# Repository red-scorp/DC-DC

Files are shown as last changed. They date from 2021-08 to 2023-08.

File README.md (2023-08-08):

```
 ____  _____   _ ____  _____    _____           _         _   
|    \|     | / |    \|     |  |  _  |___ ___  |_|___ ___| |_ 
|  |  |   --|/ /|  |  |   --|  |   __|  _| . | | | -_|  _|  _|
|____/|_____|_/ |____/|_____|  |__|  |_| |___|_| |___|___|_|  
                                             |___|
```

# DC/DC project

This project is intended to implement some simple multipurpose DC/DC buck and buck-boost converters from easy available components.
This project also features Excel based component values calculator.

I've stared this project to create stable and high quality DC/DC module for my private projects, covering most common usecases:

- Step-down to most common fixed voltages 3.3V, 5V and 12V up to 5A
- Step-up/down from 1.8V-5.5V to 3.3V and 5V up to 3A
- Step-up/down from 2.5V-12V to 3.3V and 5V up to 1A

## DCDC-12V5V5A

**DCDC-12V5V5A** is simple DC/DC step-down converter with fixed output 5V.
When used for more than 1A current it's recommended to glue a heat sink about 20x20mm in a middle of the bottom side of the board.

Preview:

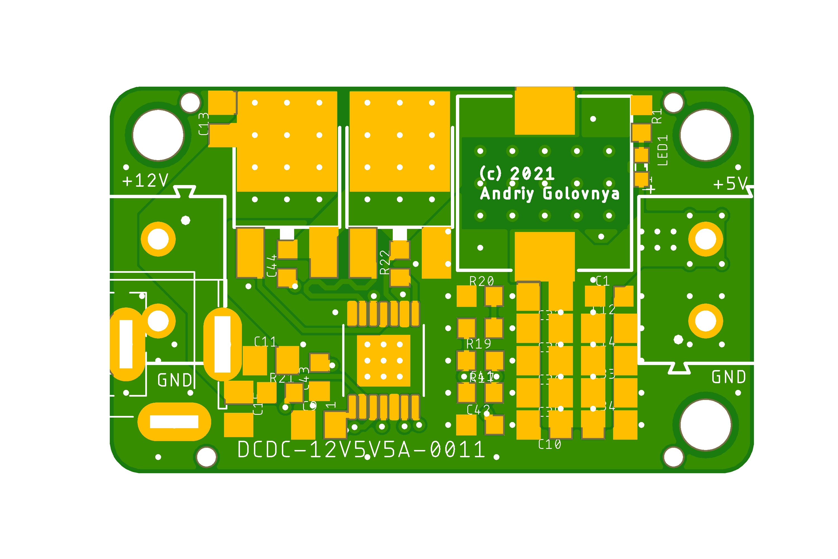
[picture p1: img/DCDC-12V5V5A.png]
DCDC-12V5V5A preview


[Schematics in PDF format](doc/DCDC-12V5V5A.pdf)

Features:

- Input: **12V (7V-24V)**
- Output: **5V**
- Current: **5A (peak 10A)**
- Switching: **500kHz**
- Efficiency: **up to 90%**
- Board size: **40x24mm**
- Based on: **Ti LM3150**

CAM files are available.
BoM and PnP files for JLCPCB are available.

## DCDC-12V3V5A

**DCDC-12V3V5A** is simple DC/DC step-down converter with fixed output 3.3V.
When used for more than 1A current it's recommended to glue a heat sink about 20x20mm in a middle of the bottom side of the board.

Preview:

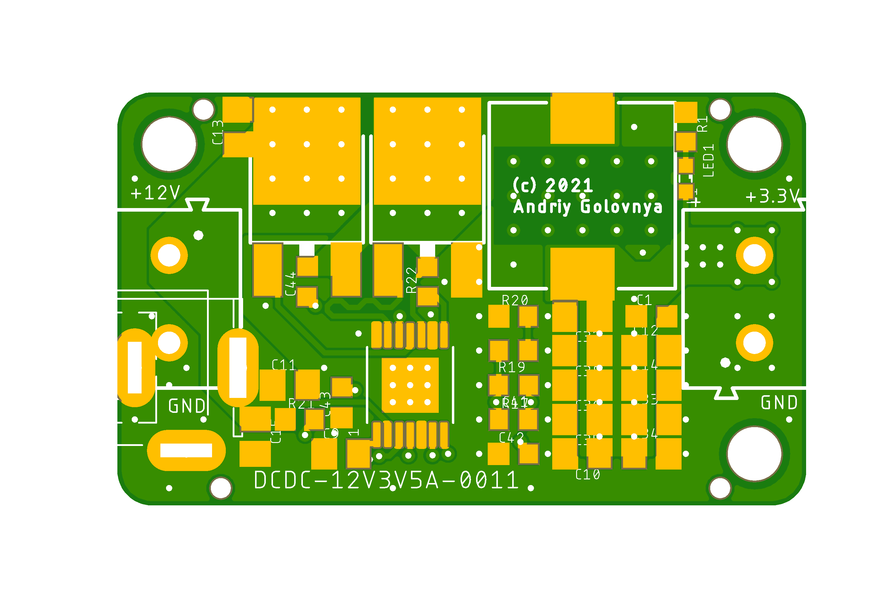
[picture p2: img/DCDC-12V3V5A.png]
DCDC-12V3V5A preview


[Schematics in PDF format](doc/DCDC-12V3V5A.pdf)

Features:

- Input: **12V (5V-24V)**
- Output: **3.3V**
- Current: **5A (peak 10A)**
- Switching: **600kHz**
- Efficiency: **up to 90%**
- Board size: **40x24mm**
- Based on: **Ti LM3150**

CAM files are available.
BoM and PnP files for JLCPCB are available.

## DCDC-18V12V5A

**DCDC-18V12V5A** is simple DC/DC step-down converter with fixed output 12V.
When used for more than 1A current it's recommended to glue a heat sink about 20x20mm in a middle of the bottom side of the board.

Preview:

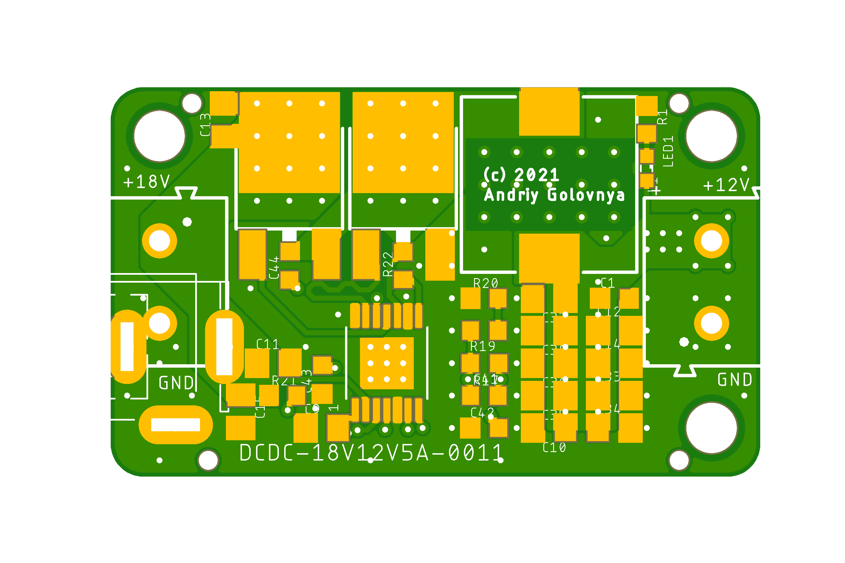
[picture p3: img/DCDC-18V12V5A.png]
DCDC-18V12V5A preview


[Schematics in PDF format](doc/DCDC-18V12V5A.pdf)

Features:

- Input: **18V (14V-24V)**
- Output: **12V**
- Current: **5A (peak 10A)**
- Switching: **500kHz**
- Efficiency: **up to 90%**
- Board size: **40x24mm**
- Based on: **Ti LM3150**

CAM files are available.
BoM and PnP files for JLCPCB are available.

## DCDC-18VXV5A

**DCDC-18VXV5A** is simple DC/DC step-down converter with selectable output 2-12V.
When used for more than 1A current it's recommended to glue a heat sink about 20x20mm in a middle of the bottom side of the board.

Preview:

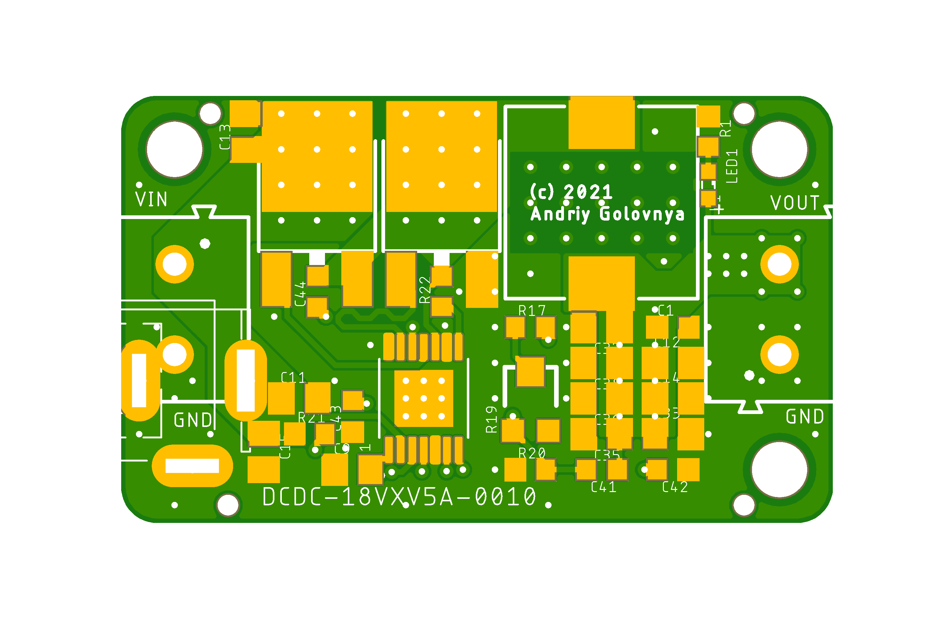
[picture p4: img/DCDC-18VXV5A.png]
DCDC-18VXV5A preview


[Schematics in PDF format](doc/DCDC-18VXV5A.pdf)

Features:

- Input: **18V (5V-24V)**
- Output: **2-12V**
- Current: **5A (peak 10A)**
- Switching: **500kHz**
- Efficiency: **up to 90%**
- Board size: **40x24mm**
- Based on: **Ti LM3150**

CAM files are available.
BoM and PnP files for JLCPCB are available.

## DCDC-5V5V3A

**DCDC-5V5V3A** is simple DC/DC step-up/down converter with selectable fixed output 3.3/5V.
When used for more than 1A current it's recommended to glue a heat sink about 20x20mm in a middle of the bottom side of the board.

Preview:

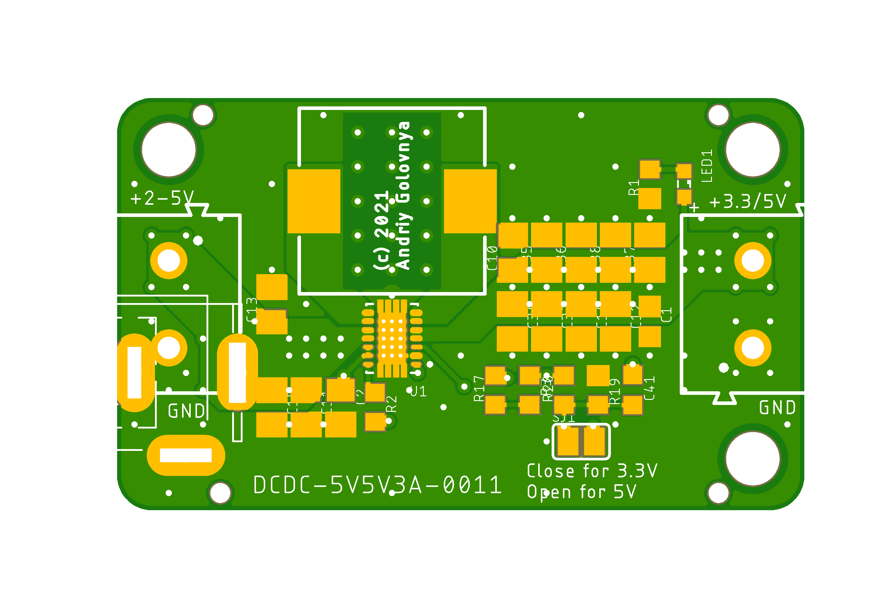
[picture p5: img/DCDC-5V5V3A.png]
DCDC-5V5V3A preview


[Schematics in PDF format](doc/DCDC-5V5V3A.pdf)

Features:

- Input: **1.8-5.5V**
- Output: **3.3/5V (select)**
- Current: **3A (peak 5A)**
- Switching: **2.4MHz**
- Efficiency: **up to 90%**
- Board size: **40x24mm**
- Based on: **Ti TPS63020**

CAM files are available.
BoM and PnP files for JLCPCB are available.

## DCDC-5VXV3A

**DCDC-5VXV3A** is simple DC/DC step-up/down converter with selectable output 1.2-5V.
When used for more than 1A current it's recommended to glue a heat sink about 20x20mm in a middle of the bottom side of the board.

Preview:

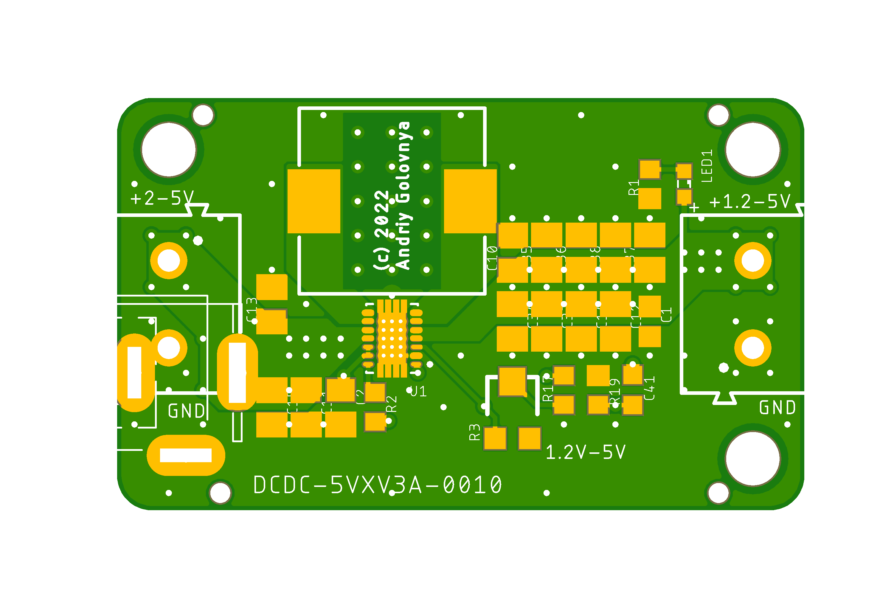
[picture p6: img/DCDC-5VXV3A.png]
DCDC-5VXV3A preview


[Schematics in PDF format](doc/DCDC-5VXV3A.pdf)

Features:

- Input: **1.8-5.5V**
- Output: **1.2-5V**
- Current: **3A (peak 5A)**
- Switching: **2.4MHz**
- Efficiency: **up to 90%**
- Board size: **40x24mm**
- Based on: **Ti TPS63020**

CAM files are available.
BoM and PnP files for JLCPCB are available.

## DCDC-12V5V1A

**DCDC-12V5V1A** is simple DC/DC step-up/down converter with selectable fixed output 3.3/5V.
When used for more than 1A current it's recommended to glue a heat sink about 20x20mm in a middle of the bottom side of the board.

Preview:

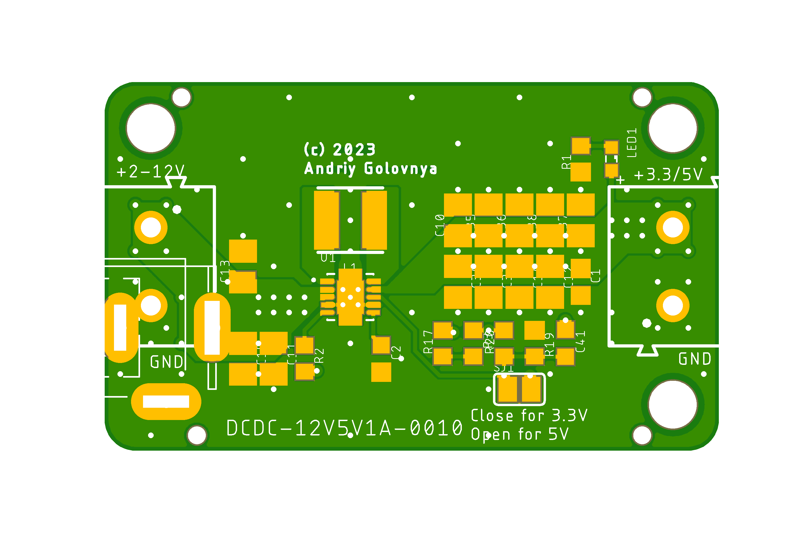
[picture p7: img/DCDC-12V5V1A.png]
DCDC-12V5V1A preview


[Schematics in PDF format](doc/DCDC-12V5V1A.pdf)

Features:

- Input: **2.5-12V**
- Output: **3.3/5V (select)**
- Current: **1A (peak 2A)**
- Switching: **2.4MHz**
- Efficiency: **up to 90%**
- Board size: **40x24mm**
- Based on: **Ti TPS63060**

CAM files are available.
BoM and PnP files for JLCPCB are available.

## DCDC-BASE-X2A

**DCDC-BASE-X2A** is base board for 2 DC/DC modules with common input and two separate outputs.
When used for more than 1A current it's recommended to glue a heat sinks about 20x20mm in a middle of the bottom side of DCDC boards before soldering them to the base board.

Preview:

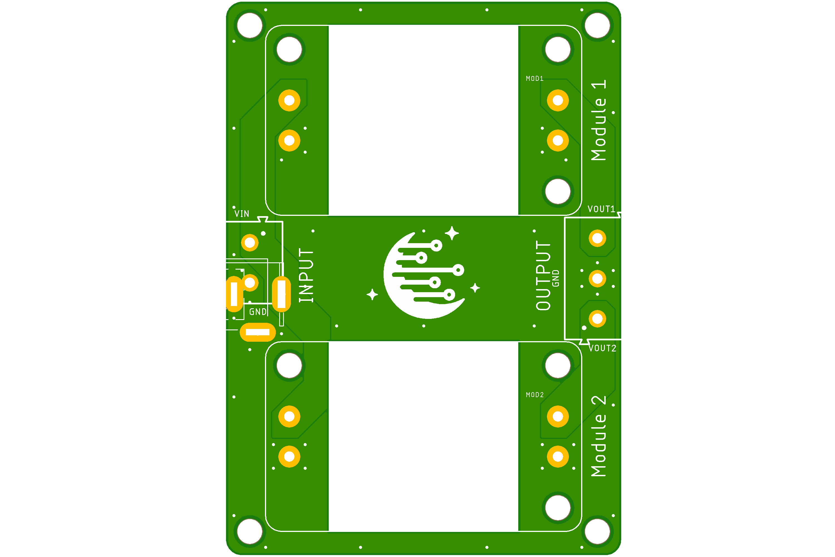
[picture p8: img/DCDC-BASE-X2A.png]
DCDC-BASE-X2A preview


[Schematics in PDF format](doc/DCDC-BASE-X2A.pdf)

Features:

- Fits two compatible DCDC modules
- Common/single input
- Two separate outputs
- Compatible with heat sinks up to 24x24mm
- Supports direct and/or hole through soldering of DCDC modules

CAM files are available.

## DCDC-BASE-X2B

**DCDC-BASE-X2B** is base board for 2 DC/DC modules with common input and two separate outputs.
When used for more than 1A current it's recommended to glue a heat sinks about 20x20mm in a middle of the bottom side of DCDC boards before soldering them to the base board.

Preview:

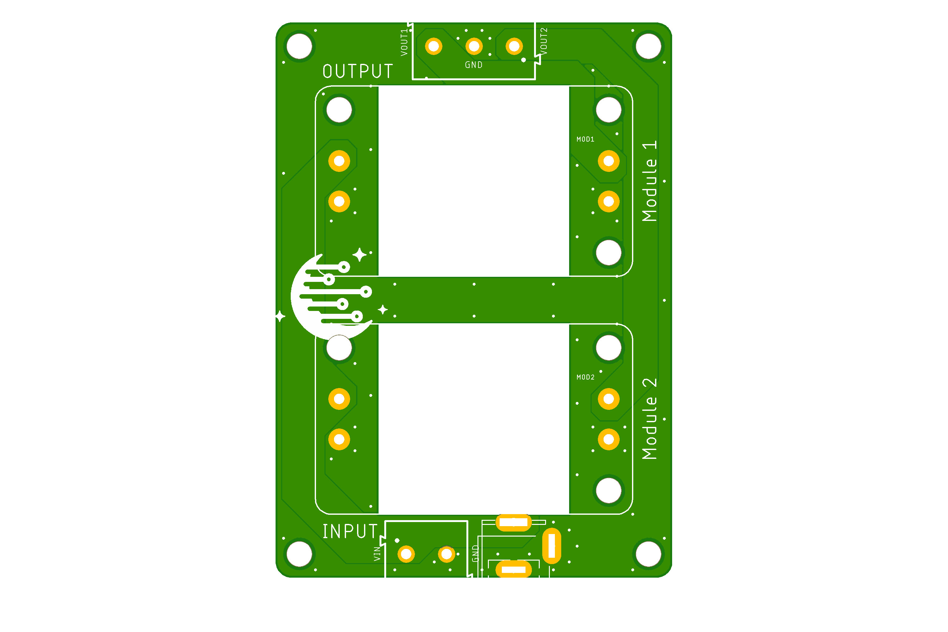
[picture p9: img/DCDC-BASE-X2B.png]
DCDC-BASE-X2B preview


[Schematics in PDF format](doc/DCDC-BASE-X2B.pdf)

Features:

- Fits two compatible DCDC modules
- Common/single input
- Two separate outputs
- Compatible with heat sinks up to 24x24mm
- Supports direct and/or hole through soldering of DCDC modules

CAM files are available.

## DCDC-BOX

**DCDC-BOX** is a enclosure for a single DCDC module, suitable for FDM and SLA 3D printing.

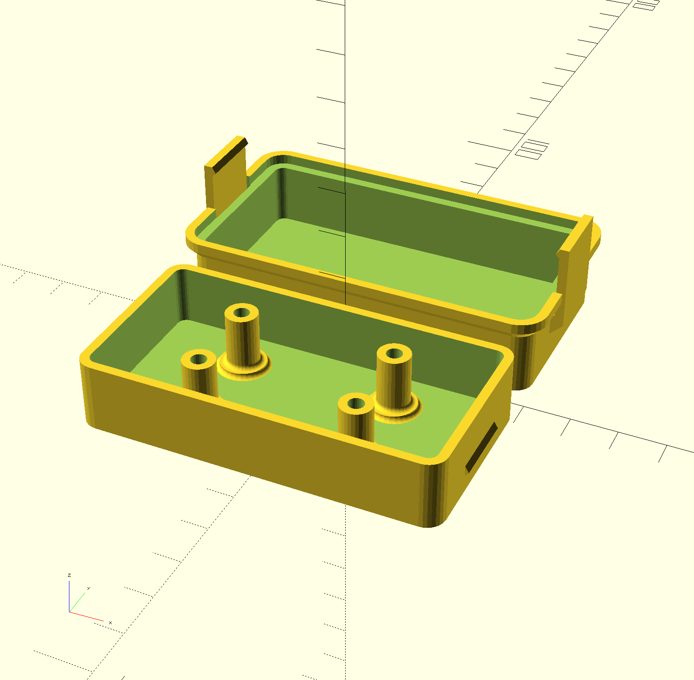
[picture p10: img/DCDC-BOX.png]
DCDC-BOX preview


STL file is available.

## DCDC-BOX-X2

**DCDC-BOX-X2** is a enclosure for a X2A and X2B base boards, suitable for FDM and SLA 3D printing.

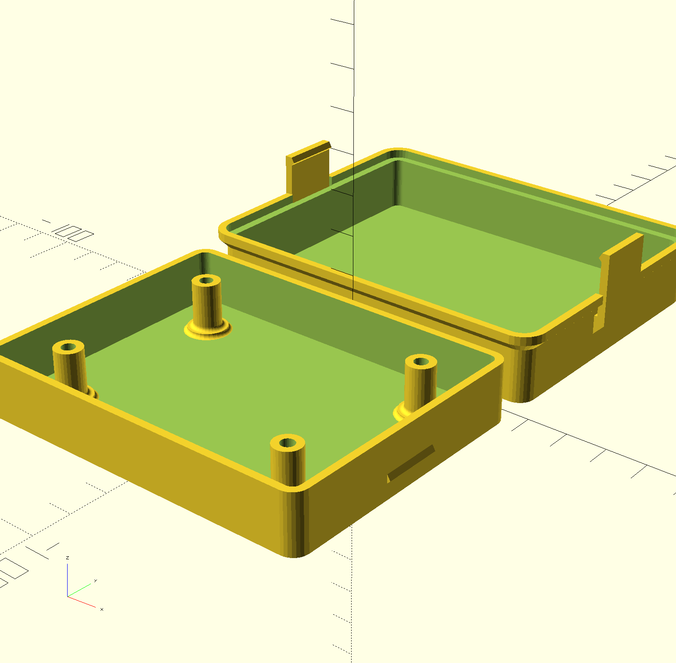
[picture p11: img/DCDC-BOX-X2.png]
DCDC-BOX-X2 preview


STL file is available.

## Links

- Interesting paper from Ti [Under the hood of a noninverting buck-boost converter](https://www.ti.com/seclit/ml/slup346/slup346.pdf)
- Product page of [Ti LM3150](https://www.ti.com/product/LM3150)
- Product page of [Ti TPS63020](https://www.ti.com/product/TPS63020)
- Product page of [Ti TPS63060](https://www.ti.com/product/TPS63060)

## How to help

Your contributions as code, resources, or finances are welcome! Please contact me directly via email at andriy.golovnya@gmail.com or through my [GitHub profile](https://github.com/red-scorp).

If you'd like to make a financial contribution, you can donate via [PayPal](http://paypal.me/redscorp) or [Ko-Fi](http://ko-fi.com/redscorp). Your support is greatly appreciated.

Thanks in advance!

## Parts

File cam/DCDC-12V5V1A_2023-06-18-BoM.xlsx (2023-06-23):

Qty | Designator | Footprint | Comment | JLCPCB Part # | Description
1 | C2 | 0603 | 100nF | C14663 | CAPACITOR, European symbol
1 | R19 | 0603 | 180k | C22827 | RESISTOR, European symbol
2 | R2, R17 | 0603 | 1M | C22935 | RESISTOR, European symbol
1 | R1 | 0603 | 1k | C21190 | RESISTOR, European symbol
1 | C1 | 0603 | 1nF | C1588 | CAPACITOR, European symbol
1 | L1 | SMD | 1.5uH | C354573 | WE-LQS SMD Power Inductor
1 | C41 | 0603 | 200pF | C1600 | CAPACITOR, European symbol
1 | R3 | 0603 | 20k | C4184 | RESISTOR, European symbol
12 | C10, C11, C12, C13, C14, C15, C33, C34, C35, C36, C37, C38 | 0805 | 22uF | C45783 | CAPACITOR, European symbol
1 | R20 | 0603 | 620k | C23219 | RESISTOR, European symbol
1 | LED1 | 0603 | GREEN | C72043 | LED
1 | U1 | WSON-10-EP(3x3) | TPS63060DSCR | C48567 | Buck-boost type Adjustable 2.5V~8V 2A 2.5V~12V DFN-10-EP(3x3) DC-DC Converters ROHS

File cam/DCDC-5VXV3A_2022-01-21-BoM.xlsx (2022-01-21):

Qty | Designator | Footprint | Comment | LCSC Part #
1 | R2 | 0603 | 1M | C22935
1 | R1 | 0603 | 3k | C4211
1 | C1 | 0603 | 1nF | C1588
1 | R3 | RES-ADJ-SMD | 200k | C128551
1 | C41 | 0603 | 200pF | C1600
1 | R19 | 0603 | 22k | C31850
13 | C2, C10, C11, C12, C13, C14, C15, C33, C34, C35, C36, C37, C38 | 0805 | 22uF | C45783
1 | L1 | IND-SMD | 3.3uH | C241408
1 | R17 | 0603 | 30k | C22984
1 | LED1 | LED_0603 | RED | C72044
1 | U1 | VSON-14_EP_3.0x4.0x0.5P | TPS63020DSJR | C15483

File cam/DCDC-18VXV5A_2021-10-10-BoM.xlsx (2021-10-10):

Qty | Designator | Footprint | Comment | LCSC Part #
2 | R1, R20 | 0603 | 10k | C25804
2 | C1, C43 | 0603 | 1nF | C1588
1 | R19 | RES-ADJ-SMD | 200k | C128551
1 | C41 | 0603 | 200pF | C1600
11 | C9, C11, C12, C13, C14, C15, C33, C35, C36, C37, C38 | 0805 | 22uF | C45783
1 | R17 | 0603 | 24k | C23352
1 | R22 | 0603 | 2k | C22975
1 | L1 | IND-SMD | 3.3uH | C241408
1 | C44 | 0603 | 470nF | C1623
1 | C42 | 0603 | 68nF | C31658
1 | R21 | 0603 | 82k | C23254
1 | LED1 | LED_0603 | GREEN | C72043
1 | U1 | HTSSOP-14_EP_4.4x5.0x0.65P | LM3150MHX/NOPB | C48112
2 | Q9, Q10 | TO-252-2 | NCE3050K | C127863

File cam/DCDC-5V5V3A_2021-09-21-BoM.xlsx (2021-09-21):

Qty | Designator | Footprint | Comment | LCSC Part #
1 | R19 | 0603 | 180k | C22827
2 | R2, R17 | 0603 | 1M | C22935
1 | R1 | 0603 | 1k | C21190
1 | C1 | 0603 | 1nF | C1588
1 | C41 | 0603 | 200pF | C1600
13 | C2, C10, C11, C12, C13, C14, C15, C33, C34, C35, C36, C37, C38 | 0805 | 22uF | C45783
1 | L1 | IND-SMD | 3.3uH | C241408
1 | R20 | 0603 | 620k | C23219
1 | LED1 | LED_0603 | GREEN | C72043
1 | U1 | VSON-14_EP_3.0x4.0x0.5P | TPS63020DSJR | C15483
1 | R3 | 0603 | 20k | C4184

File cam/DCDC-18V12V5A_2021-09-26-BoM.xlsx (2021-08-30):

Qty | Designator | Footprint | Comment | LCSC Part #
2 | R1, R20 | 0603 | 10k | C25804
2 | C1, C43 | 0603 | 1nF | C1588
2 | R17, R21 | 0603 | 200k | C25811
1 | C41 | 0603 | 200pF | C1600
13 | C9, C10, C11, C12, C13, C14, C15, C33, C34, C35, C36, C37, C38 | 0805 | 22uF | C45783
1 | R22 | 0603 | 2k | C22975
1 | L1 | IND-SMD | 3.3uH | C241408
1 | R19 | 0603 | 470 | C23179
1 | C44 | 0603 | 470nF | C1623
1 | C42 | 0603 | 68nF | C31658
1 | LED1 | LED_0603 | GREEN | C72043
1 | U1 | HTSSOP-14_EP_4.4x5.0x0.65P | LM3150MHX/NOPB | C48112
2 | Q9, Q10 | TO-252-2 | NCE3050K | C127863

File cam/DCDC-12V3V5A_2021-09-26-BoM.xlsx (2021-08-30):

Qty | Designator | Footprint | Comment | LCSC Part #
1 | R20 | 0603 | 10k | C25804
1 | R1 | 0603 | 1k | C21190
2 | C1, C43 | 0603 | 1nF | C1588
1 | C41 | 0603 | 200pF | C1600
13 | C9, C10, C11, C12, C13, C14, C15, C33, C34, C35, C36, C37, C38 | 0805 | 22uF | C45783
1 | R22 | 0603 | 2k | C22975
1 | L1 | IND-SMD | 3.3uH | C241408
1 | R19 | 0603 | 330 | C23138
1 | C44 | 0603 | 470nF | C1623
2 | R17, R21 | 0603 | 47k | C25819
1 | C42 | 0603 | 68nF | C31658
1 | LED1 | LED_0603 | GREEN | C72043
1 | U1 | HTSSOP-14_EP_4.4x5.0x0.65P | LM3150MHX/NOPB | C48112
2 | Q9, Q10 | TO-252-2 | NCE3050K | C127863

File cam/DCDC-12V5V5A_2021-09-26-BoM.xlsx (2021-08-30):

Qty | Designator | Footprint | Comment | LCSC Part #
1 | R19 | 0603 | 100 | C22775
1 | R20 | 0603 | 10k | C25804
2 | C1, C43 | 0603 | 1nF | C1588
1 | C41 | 0603 | 200pF | C1600
13 | C9, C10, C11, C12, C13, C14, C15, C33, C34, C35, C36, C37, C38 | 0805 | 22uF | C45783
2 | R1, R22 | 0603 | 2k | C22975
1 | L1 | IND-SMD | 3.3uH | C241408
1 | C44 | 0603 | 470nF | C1623
1 | C42 | 0603 | 68nF | C31658
1 | R17 | 0603 | 75k | C23242
1 | R21 | 0603 | 82k | C23254
1 | LED1 | LED_0603 | GREEN | C72043
1 | U1 | HTSSOP-14_EP_4.4x5.0x0.65P | LM3150MHX/NOPB | C48112
2 | Q9, Q10 | TO-252-2 | NCE3050K | C127863

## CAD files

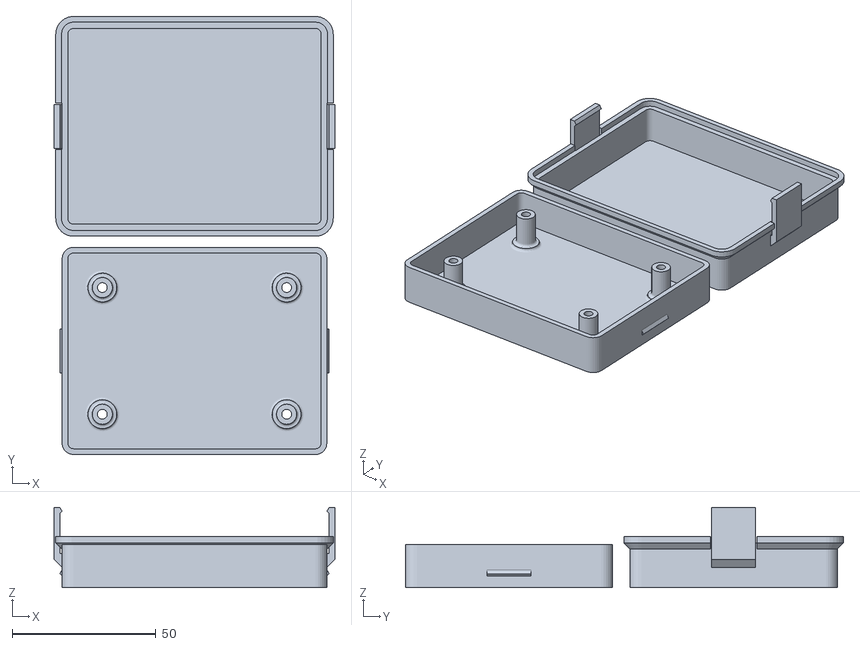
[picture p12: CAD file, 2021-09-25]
3d/DCDC-BOX-X2.stl
97.6 x 152.2 x 27.9

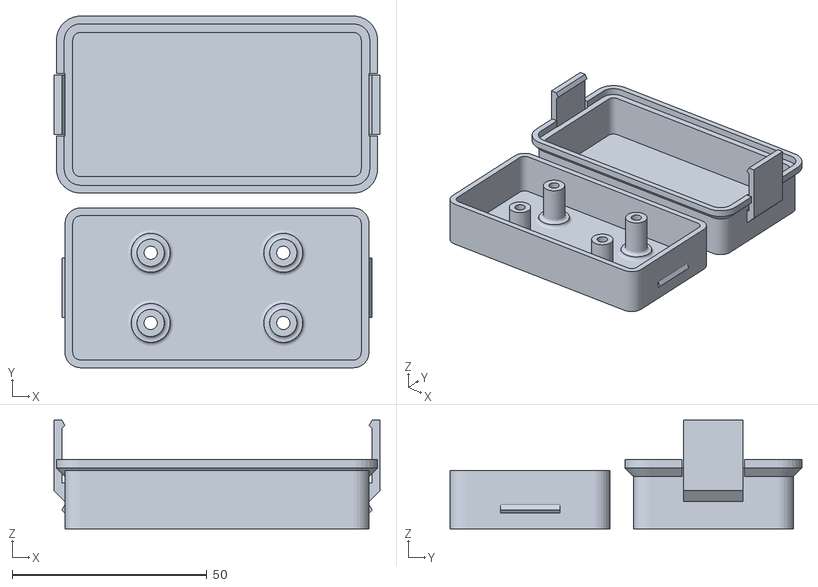
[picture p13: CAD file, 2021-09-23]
3d/DCDC-BOX.stl
83.6 x 90.2 x 27.9

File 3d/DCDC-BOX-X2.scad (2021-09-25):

/*  To view the 3D render or to export the .STL file, open this file with openscad (it is free and opensource).
    For more information, see the pdf attached.

    This work is licensed under a Creative Commons Attribution 4.0 International License.

    Note that the default parameter (at the top of the file) get overridden
    by the ones (at the bottom of the file) needed to satisfy your requirements.
    Modifying the values of the first set will have no effect, as the second set will
    still override them.

    Downloaded from www.sol75.com
*/

$fs=0.1;

//Assigned from req, not DOF
hole_distance_x = 30;
hole_distance_y = 45;

lh1 = 8; //Internal, from the bottom to the lower surface of the board
lh2 = 8; //Internal, from the top of the board, to the top surface of the box

d_screw = 3;
use_latch = 1;

use_trapped_nut = 0;// 0= nuts from below, 1= nuts in the colum

// Length = internal length of the walls
lx = 45;
ly = 55;
r_in = 2;
col_wall_t = 1; //material around the screw

// LATCH
latch_w = 10;
latch_l = 12;
latch_t = 0.8;
wedge_out = 0.8;// box_wedge to ease fittings NB:is asymetric!
wedge_angle = 30;
wedge_pos = 5;
//External screw fixture
scew_fixture_stick_out = d_screw+2;
screw_fixture_width    = d_screw*3;

//Printer settings
// How much to compenetrate
p0 = 0.01;
//Toleance as difference hole diameter vs peg diameter good tolerance
min_tol = 0.3;
min_layer_t = 0.2; //Used for bridges over holes, which will be broken away  

max_overhang = 45; // 90 would be a bridge

tx = 1.8;
ty = 0.8;
tz = 1.2;

nut_width = 6.01; // across corners
nut_h = 2.4;
// === DERIVED PARAMETERS ===
r_out = (tx<ty)?tx:ty;
t_out = r_out;// Thickness of the outer skirt on the lid
wedge_h_lwr = wedge_out;
wedge_h_upp = wedge_out/tan(wedge_angle);

fixture_width = (use_latch==0)?screw_fixture_width:latch_w;

A0_e_enclosure_0_STAND_ALONE_PRINT();
module A0_e_enclosure_0_STAND_ALONE_PRINT(){
    color("LightSteelBlue"){
        translate([0,-ly/2 - 2*tx ,0])box_bottom();
        translate([0,ly/2 + 2*tx + t_out ,0]) box_lid();
    }
}

//A0_e_enclosure_0_NULL();
module A0_e_enclosure_0_NULL(){
    color("LightSteelBlue"){
        box_bottom();
        translate([0,0,3*(lh2+lh1+tz)])rotate([0,180,0]) box_lid();
    }
}

//!box_bottom();
module box_bottom(){
      difference(){
                //Bulk
                translate([0,0,(tz+lh1)/2]) roundedBox(x= lx + 2*ty, y= ly + 2*tx, z=lh1+tz, r = r_out + r_in);
                //Take out internal volume
                translate([0,0,(tz+lh1)/2+ tz ]) roundedBox(x = lx ,y =ly,z=lh1 + tz, r = r_in);
                
                if( use_trapped_nut == 0){
                translate([0,0,-tz]) place_support() nut_negative(); 
                }
           }

        //Add support columns, but make sure they do not spill out of the box
        intersection(){
            if( use_trapped_nut ==0){
                place_support() support_column2(); 
            }else{
                place_support() support_column(); 
            }
            translate([0,0,(tz+lh1)/2]) cube(size=[lx + ty,ly + tx, lh1+tz],center = true);
        }

        if(use_latch==1){
            //Add wedges for latches
            translate([lx/2+ty, 0, wedge_pos]) asym_wedge(l = latch_w,wedge_out = wedge_out, angle = wedge_angle);
            rotate([0,0,180]) translate([lx/2+ty,0, wedge_pos]) asym_wedge(l= latch_w,wedge_out = wedge_out, angle = wedge_angle);
        }else{
            translate([lx/2 +ty,0,0]) bolt_support(height =lh1+tz,
                                                   width=screw_fixture_width,
                                                   stick_out = scew_fixture_stick_out,t= tx,t_top = tz );
            rotate([0,0,180])translate([lx/2 + ty,0,0]) bolt_support(height =lh1+tz,
                                                                     width = screw_fixture_width,
                                                                     stick_out = scew_fixture_stick_out,
                                                                     t= tx,t_top = tz );
            }
}


module place_support(){
      translate([-hole_distance_x/2,-hole_distance_y/2,tz]) rotate([0,0, 45]) children();
      translate([ hole_distance_x/2, hole_distance_y/2,tz]) rotate([0,0,-90 -45]) children();
      translate([-hole_distance_x/2, hole_distance_y/2,tz]) rotate([0,0,-45])children();
      translate([ hole_distance_x/2,-hole_distance_y/2,tz]) rotate([0,0, 90 +45]) children();
 }
//!support_column();
 
module support_column(){
    //Columns with space to insert a nut
    nut_across_flat = (nut_width)/2*tan(60) + min_tol;
    column_d_out =d_screw + 2*col_wall_t;
    d_hole = d_screw + min_tol;
    D0= sqrt( pow(column_d_out/2,2) - pow( nut_across_flat/2,2) );
    top_h = min(tz*2,2);
    module nut_and_exit(){
       hull(){
            cylinder(d =nut_width + min_tol, h =nut_h + min_tol, center = false, $fn = 6);
            translate([column_d_out/2,0,0])cylinder(d =nut_width + min_tol, h =nut_h + min_tol, center = false, $fn = 6);
       }
       translate([d_screw/2 + D0,0, nut_h + min_tol+ top_h - p0])cube([d_screw, column_d_out, 2*top_h ],center = true);
    }

    difference(){
           union(){
             translate([0,0,-p0])cylinder(d=column_d_out,h =lh1+p0 ,center=false);
             translate([0,0,-p0])cylinder(d1 =column_d_out + 2 ,d2=column_d_out,h =1 ,center=false);
           }
           translate([0,0,-2*p0])cylinder(d=d_hole,h =1.1*lh1 ,center=false);
           // groove for the nut
           translate([0,0,lh1 - top_h - (nut_h + min_tol)]) nut_and_exit();
           // rectify hole to avoid strange bridges
           rotate([0,0,90])translate([0,0,lh1])cube([nut_across_flat, d_hole, 2*top_h + p0],center = true);
    }
}

//!support_column2();
module support_column2(){
    //The nut is placed on the outer surface of the box bottom
    column_d_base = nut_width + 2*col_wall_t;
    column_d_out  = d_screw + 2*col_wall_t;
    base_h = (nut_h + min_tol) - tz + 3*min_layer_t ; 
    d_hole = d_screw + min_tol;
    fillet = 1;
    points = [ [0,-tz],
               [column_d_base/2 +fillet,-tz],
               [column_d_base/2 +fillet,0],
               [column_d_base/2,0],
               [column_d_base/2,base_h],
               [column_d_out/2,base_h], 
               [column_d_out/2,lh1+p0 ],
               [0,lh1+p0 ],
             ];
    
    difference(){
        rotate_extrude() offset(r= -fillet) offset(r =fillet) polygon(points);
        translate([0,0,-tz])nut_negative();
    }

}

//!nut_negative(); 
module nut_negative(){
     nut_across_flat = (nut_width)/2*tan(60) + min_tol;
     nut_side = nut_width/2;
     d_hole = d_screw + min_tol;
    //Empty space to house the nut 
    translate([0,0,-p0])linear_extrude(nut_h + min_tol,center = false) offset(min_tol) circle(d = nut_width, $fn = 6);
     translate([0,0,nut_h + min_tol -1.1*p0]){
        translate([0,0,min_layer_t/2]) cube([d_hole,nut_across_flat,min_layer_t],center = true); 
        translate([0,0,min_layer_t*1.5-p0*1.1]) cube([d_hole,d_hole,min_layer_t],center = true); 
        
         translate([0,0, min_layer_t*2-2.1*p0])cylinder(d =d_hole, h = tz + lh1, center = false);
     }
}

//!translate([2*lx,0,0])box_lid();
module box_lid(){
    base_x = lx + 2*ty;
    base_y = ly + 2*tx;

    stick_out = (min_tol/2 + t_out);
    half_skirt = stick_out;
    difference(){
       union(){
          //Base
           translate([0,0,(tz+lh2)/2]) roundedBox(x =base_x ,y =base_y,z=lh2+tz,r =  r_out + r_in);
           //skirt
           translate([0,0,(tz+lh2)]) rotate([0,180,0]) roundedBox_champfered_edge(x = base_x +2*stick_out,
                 y = base_y + 2*stick_out,
                 z =2*half_skirt,
                 r= r_out+r_in+stick_out,champfer_h=half_skirt);
       }

       //Take out internal volume
       translate([0,0, (lh2+tz)/2+ tz ]) roundedBox(x= lx, y= ly, z= lh2 + tz, r = r_in);
       translate([0,0, lh2 + tz + half_skirt-p0]) roundedBox(x= base_x + min_tol, y=base_y+ min_tol, z=2*half_skirt, r = r_in + r_out + min_tol/2);

          //Take out space for latch
          translate([lx/2 + ty+stick_out+p0,0,lh2+tz+p0]) cube([2*stick_out,fixture_width + 2*min_tol,2*half_skirt],center=true);
          rotate([0,0,180])translate([lx/2 + ty+stick_out+p0,0,lh2+tz+p0]) cube([2*stick_out,fixture_width  + 2*min_tol,2*half_skirt],center=true);
     }
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

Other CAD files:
3d/DCDC-BOX.scad

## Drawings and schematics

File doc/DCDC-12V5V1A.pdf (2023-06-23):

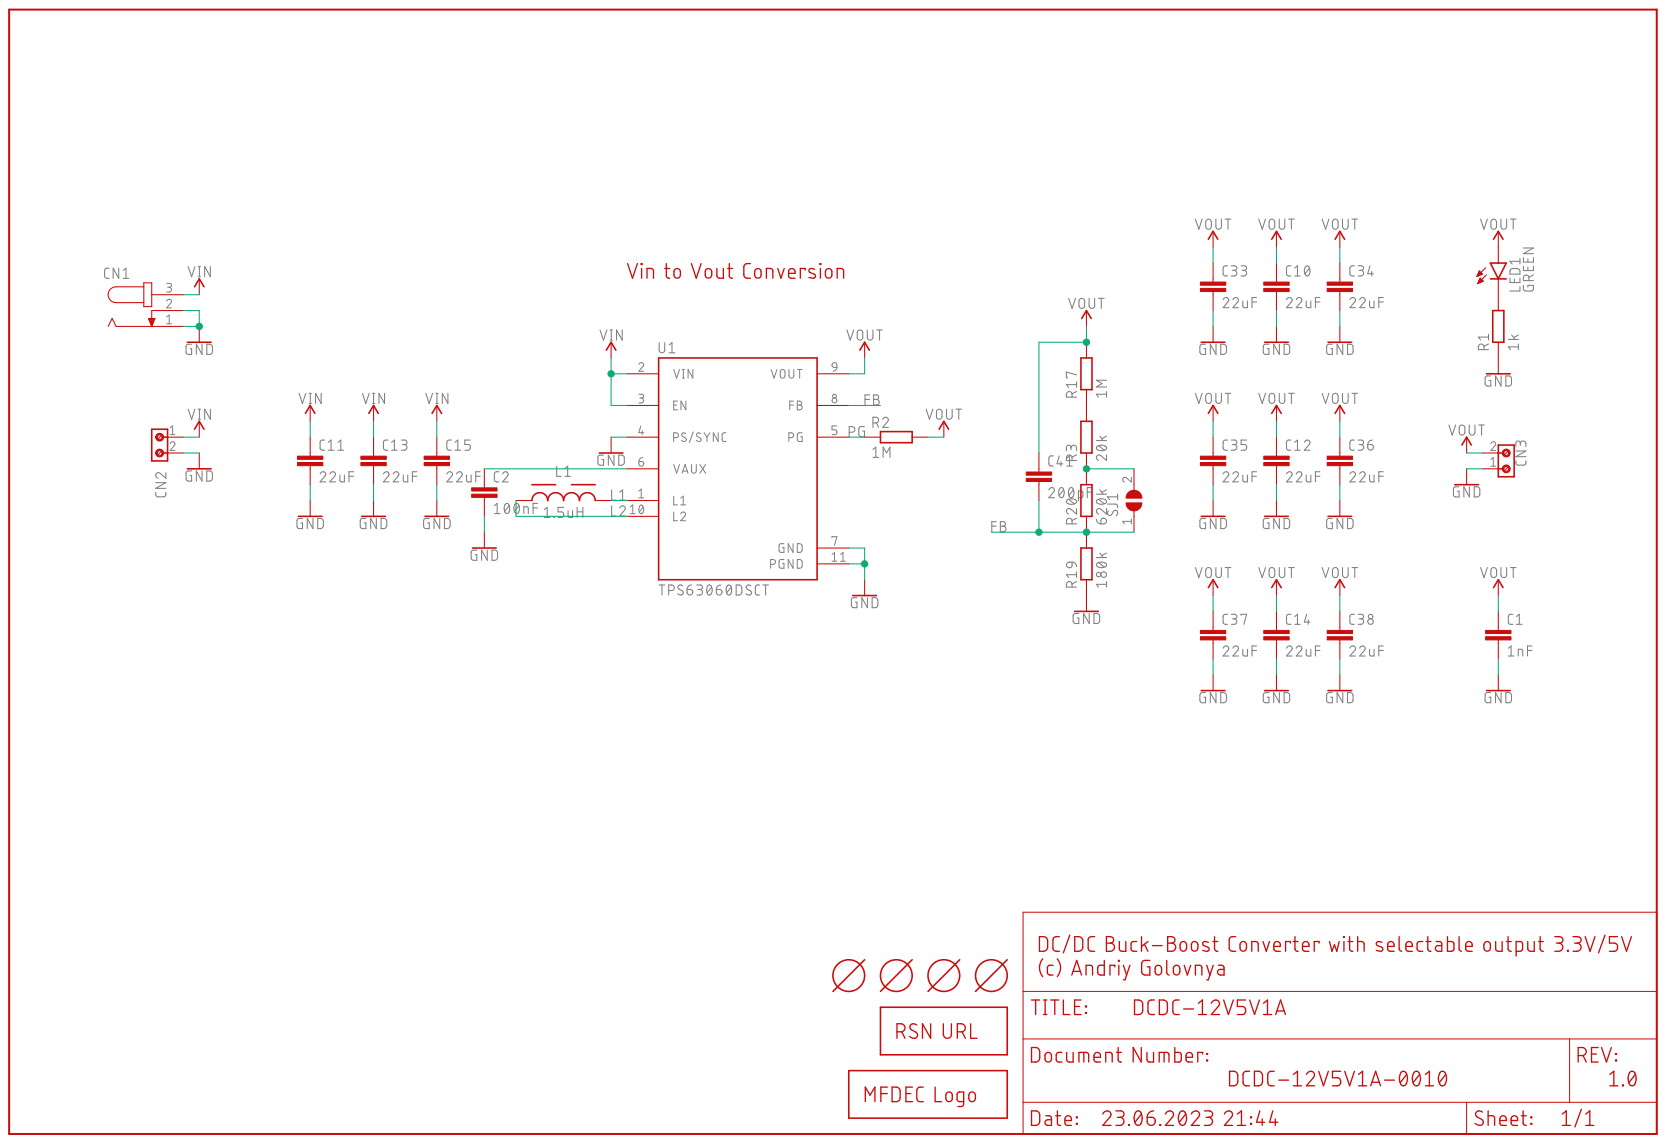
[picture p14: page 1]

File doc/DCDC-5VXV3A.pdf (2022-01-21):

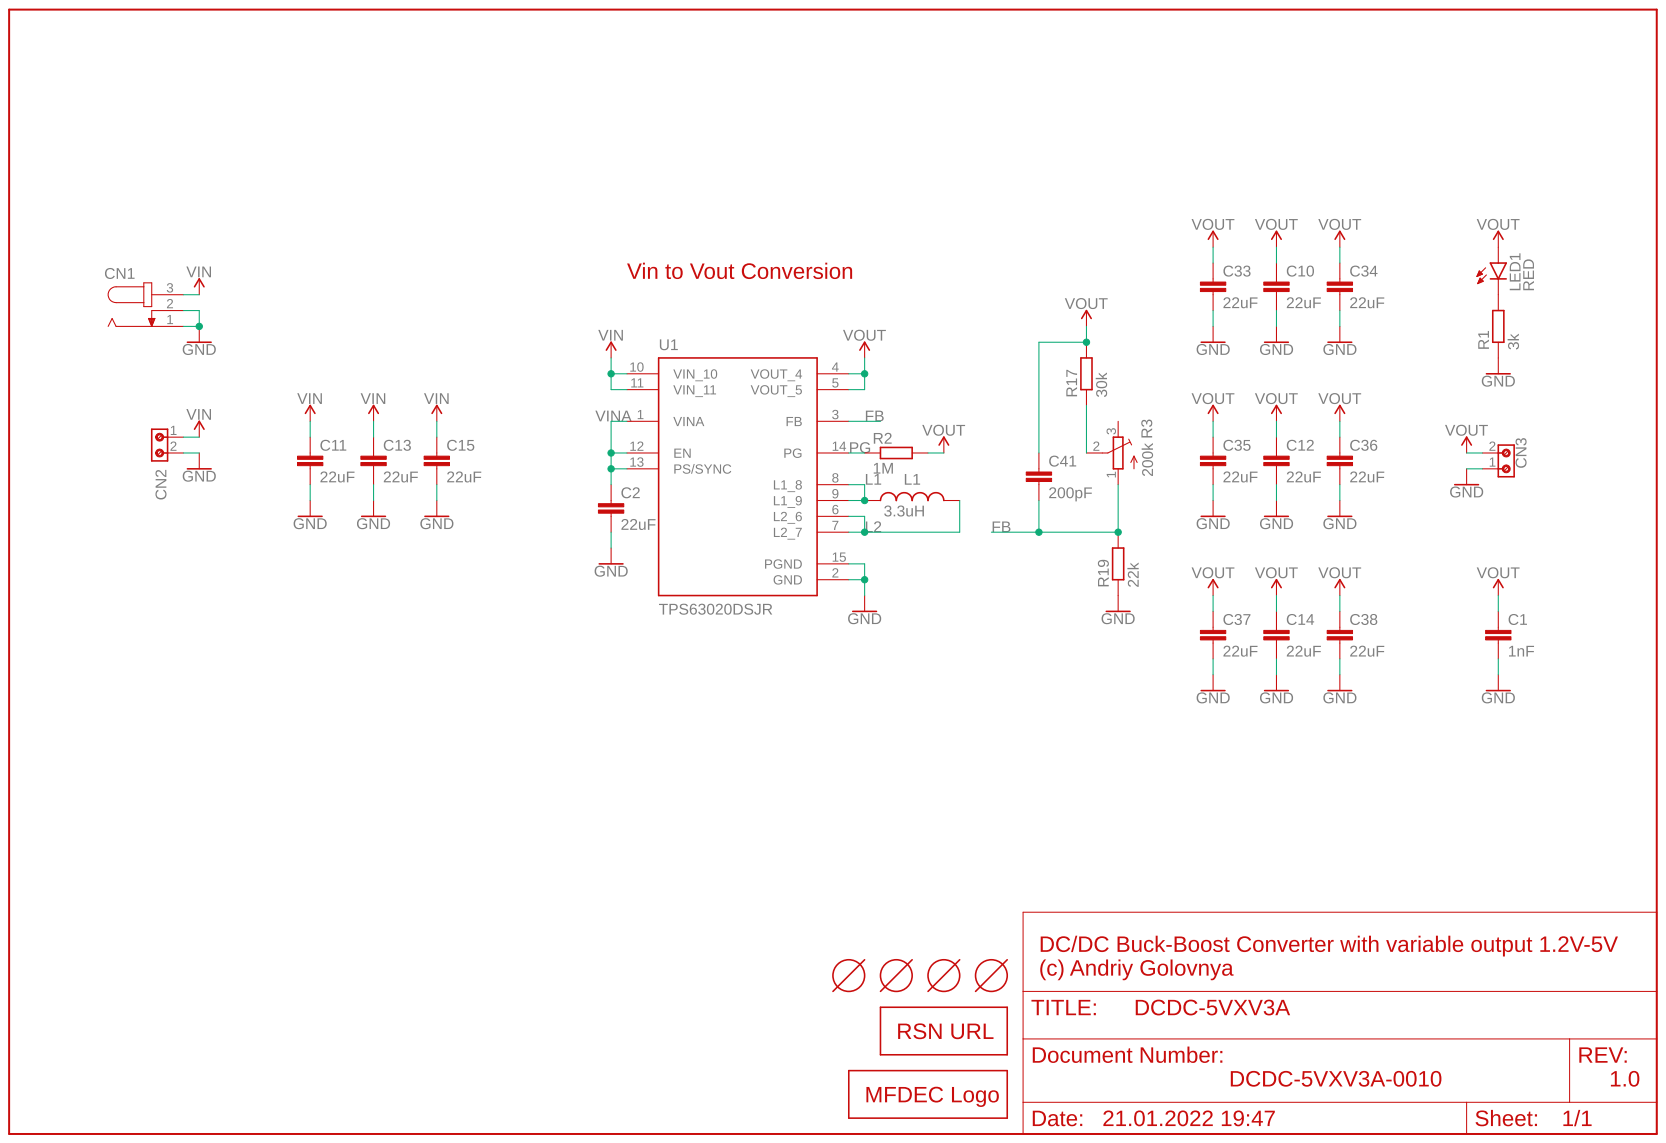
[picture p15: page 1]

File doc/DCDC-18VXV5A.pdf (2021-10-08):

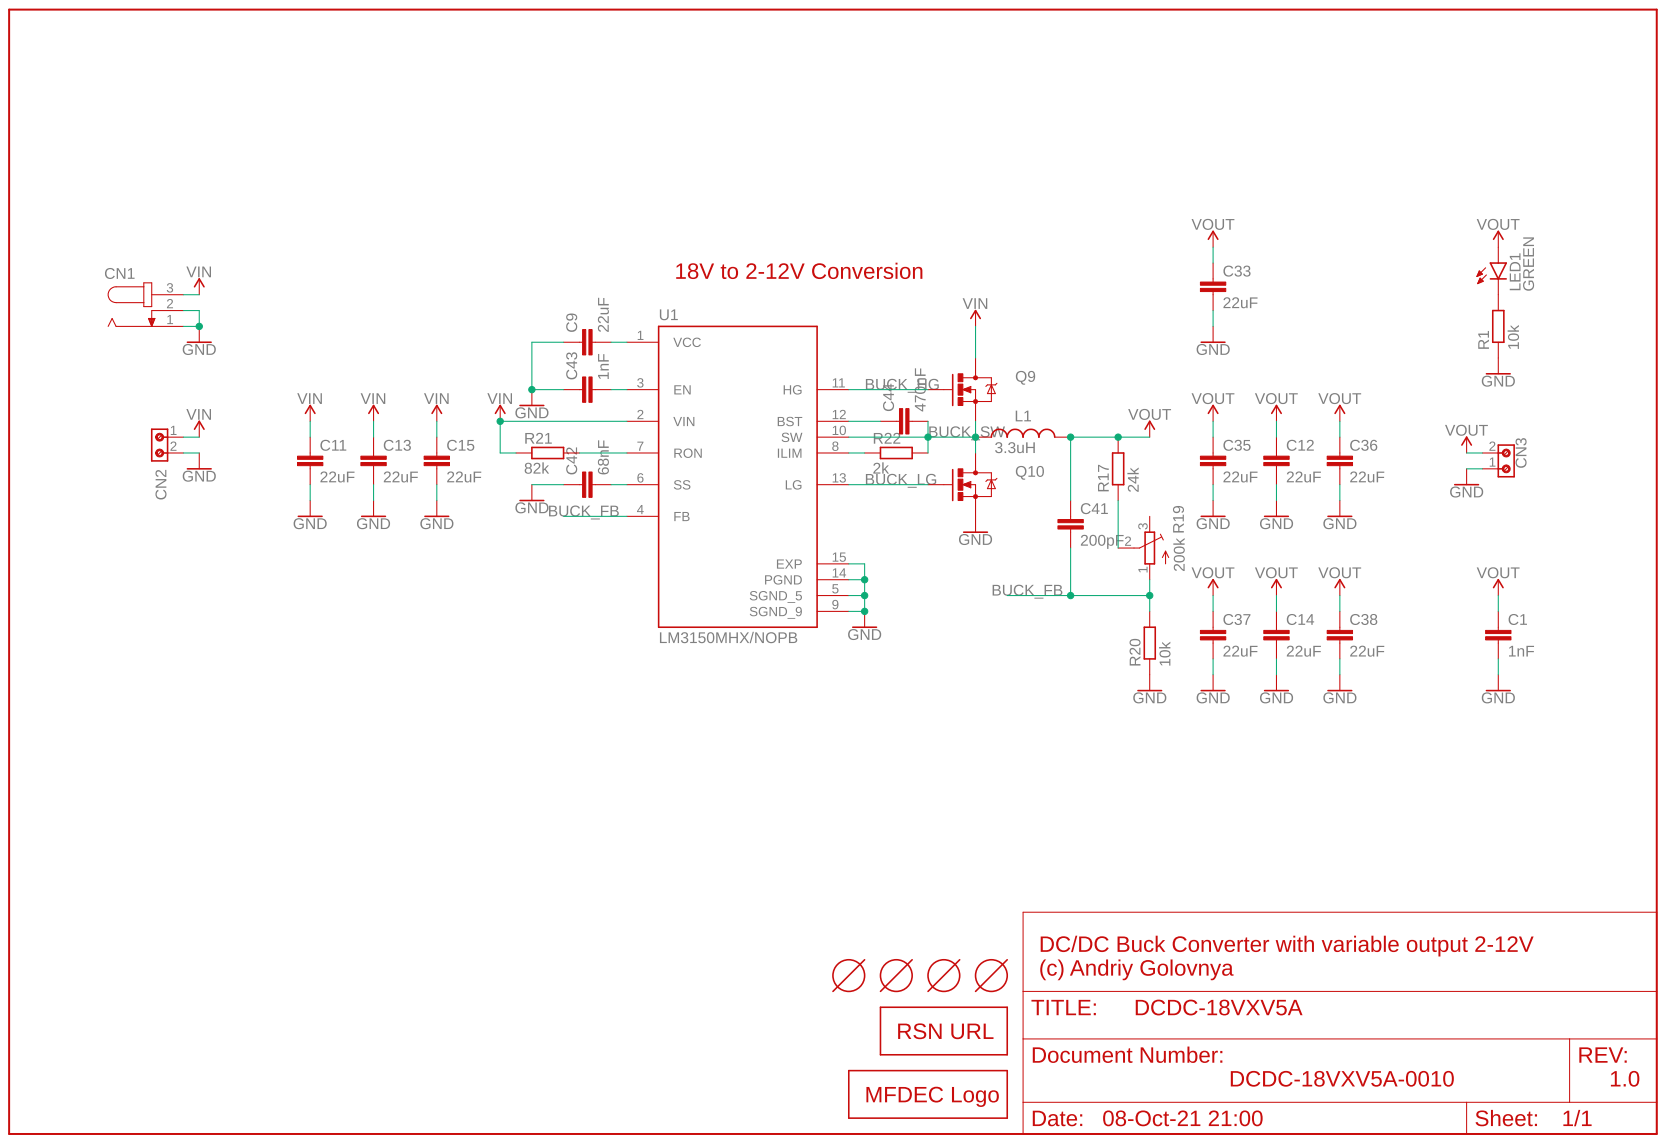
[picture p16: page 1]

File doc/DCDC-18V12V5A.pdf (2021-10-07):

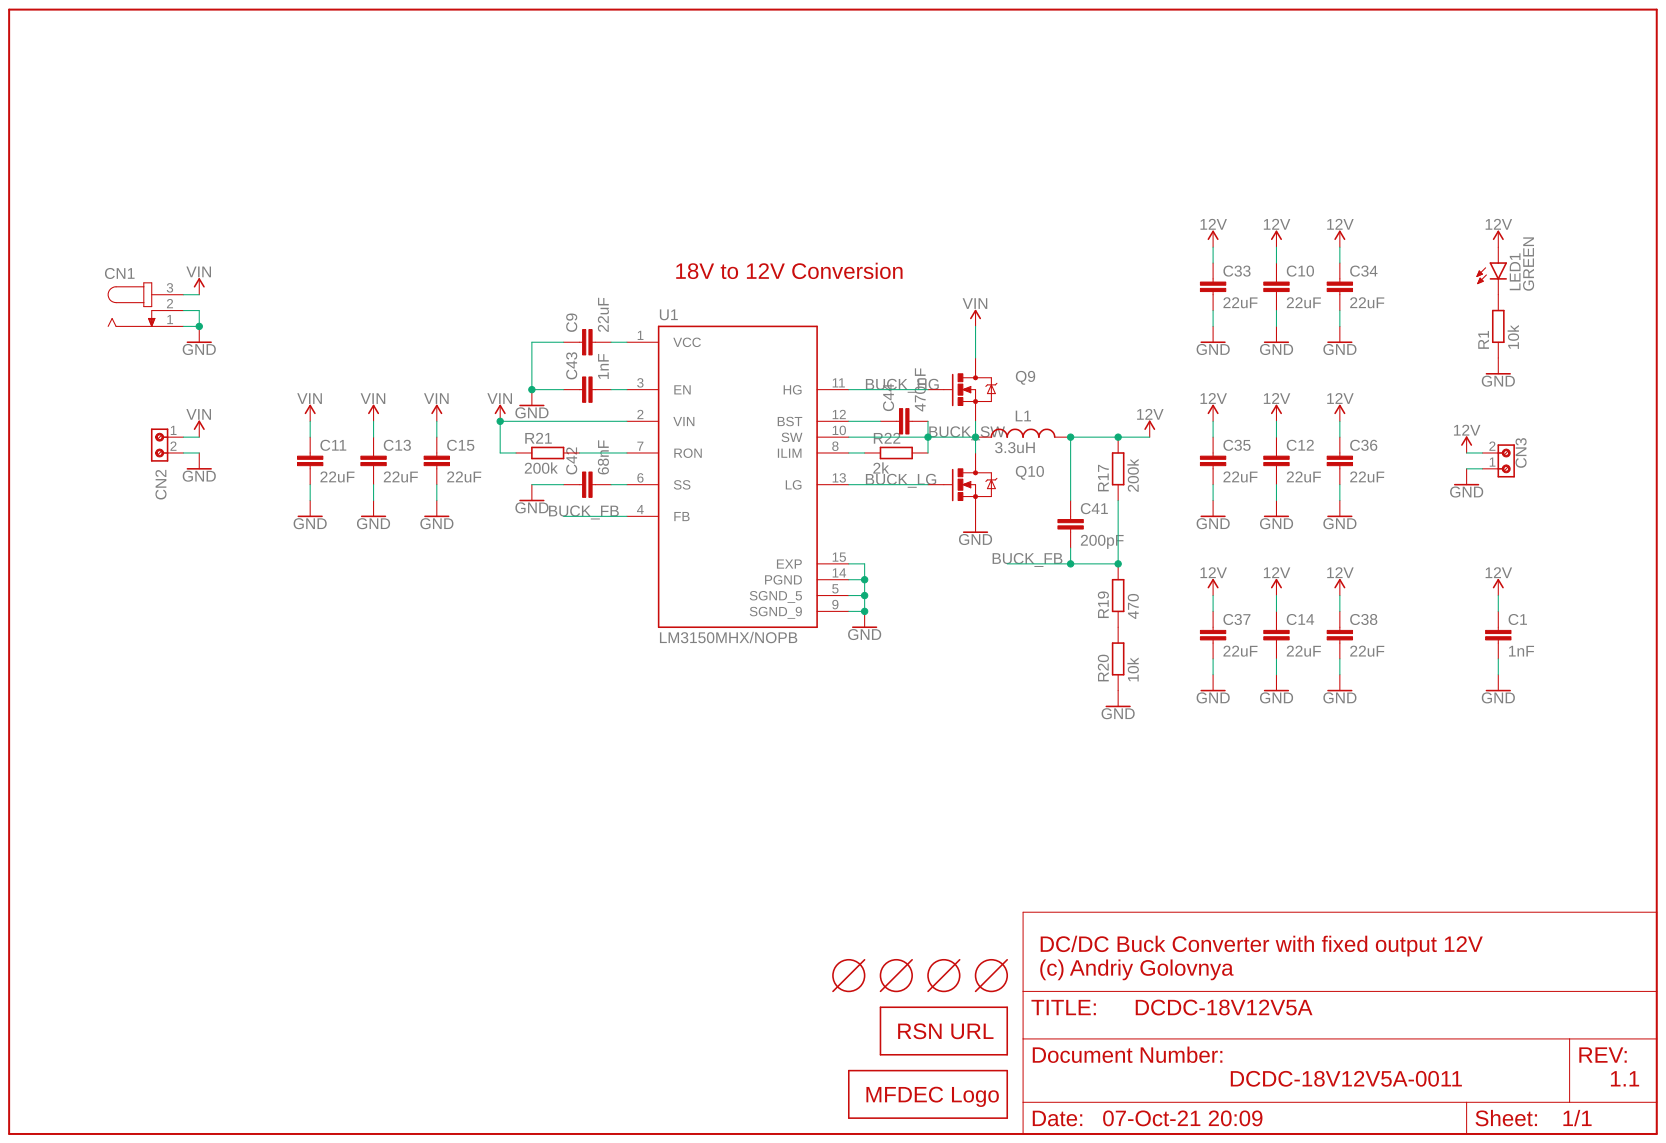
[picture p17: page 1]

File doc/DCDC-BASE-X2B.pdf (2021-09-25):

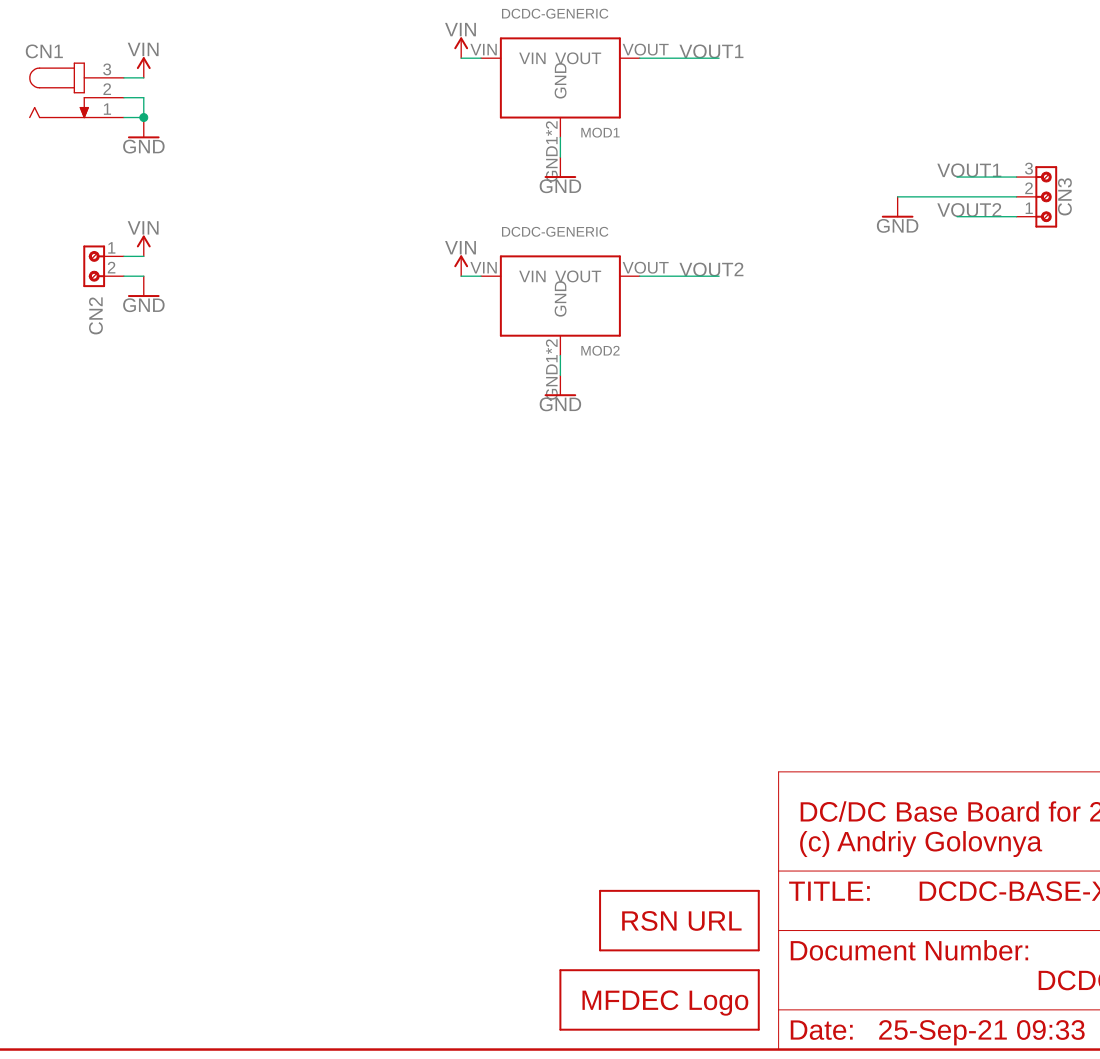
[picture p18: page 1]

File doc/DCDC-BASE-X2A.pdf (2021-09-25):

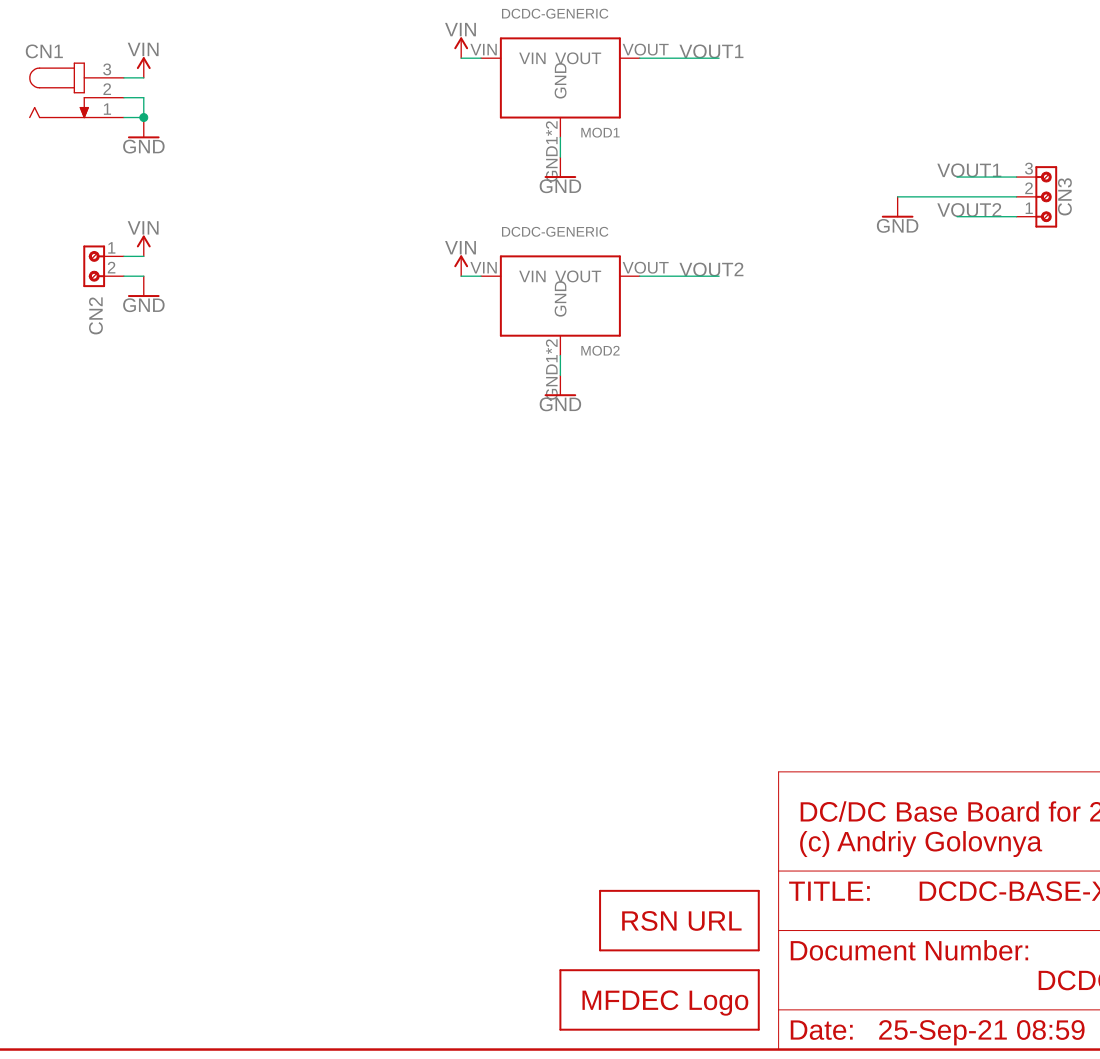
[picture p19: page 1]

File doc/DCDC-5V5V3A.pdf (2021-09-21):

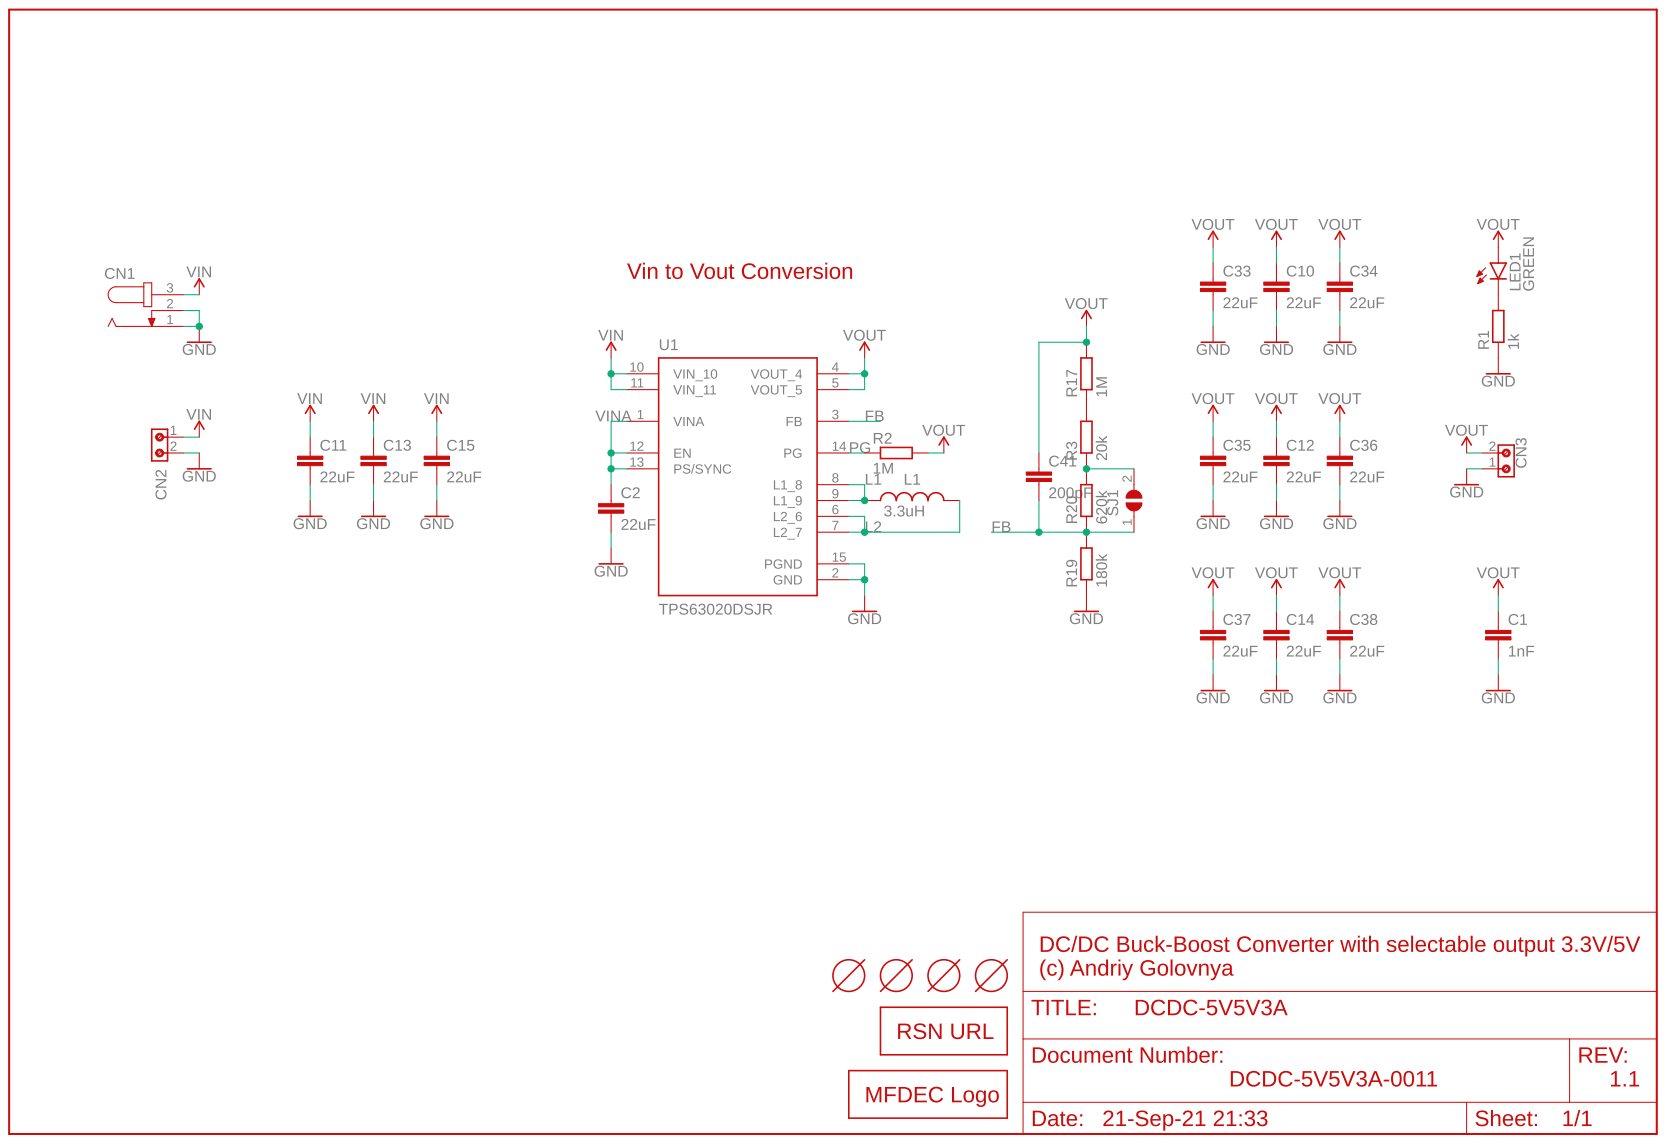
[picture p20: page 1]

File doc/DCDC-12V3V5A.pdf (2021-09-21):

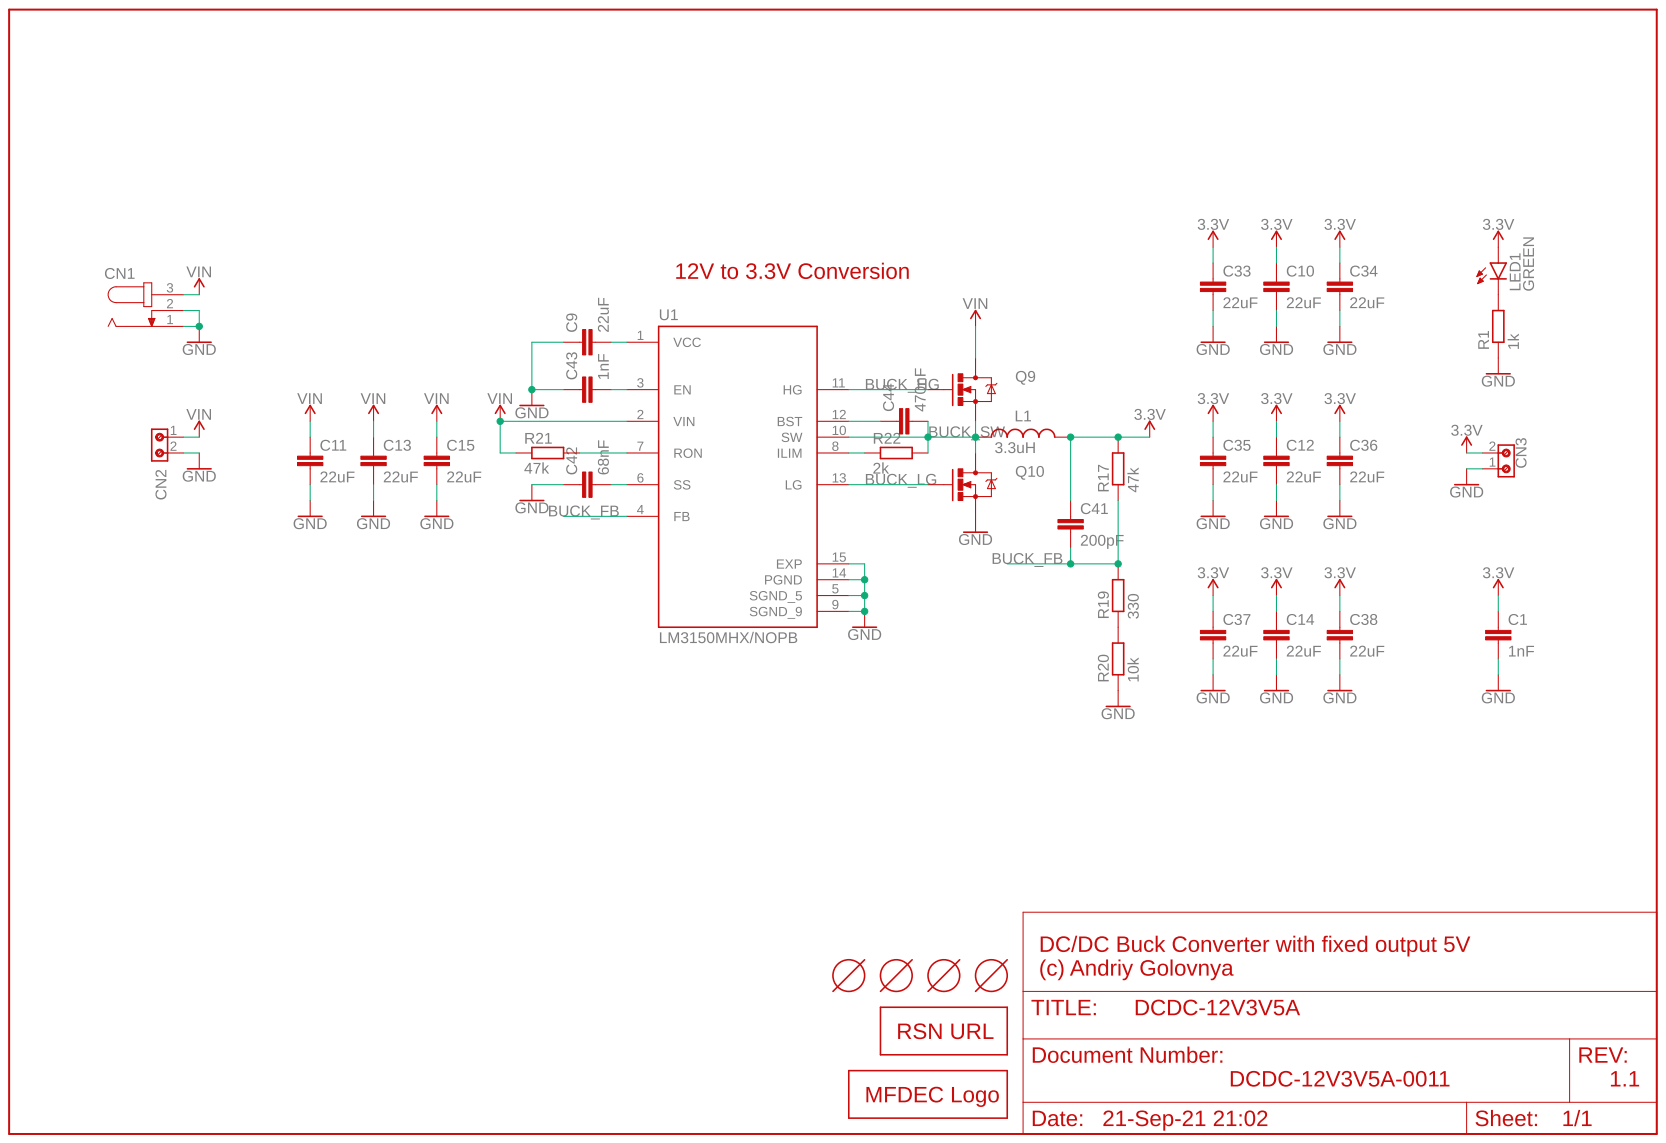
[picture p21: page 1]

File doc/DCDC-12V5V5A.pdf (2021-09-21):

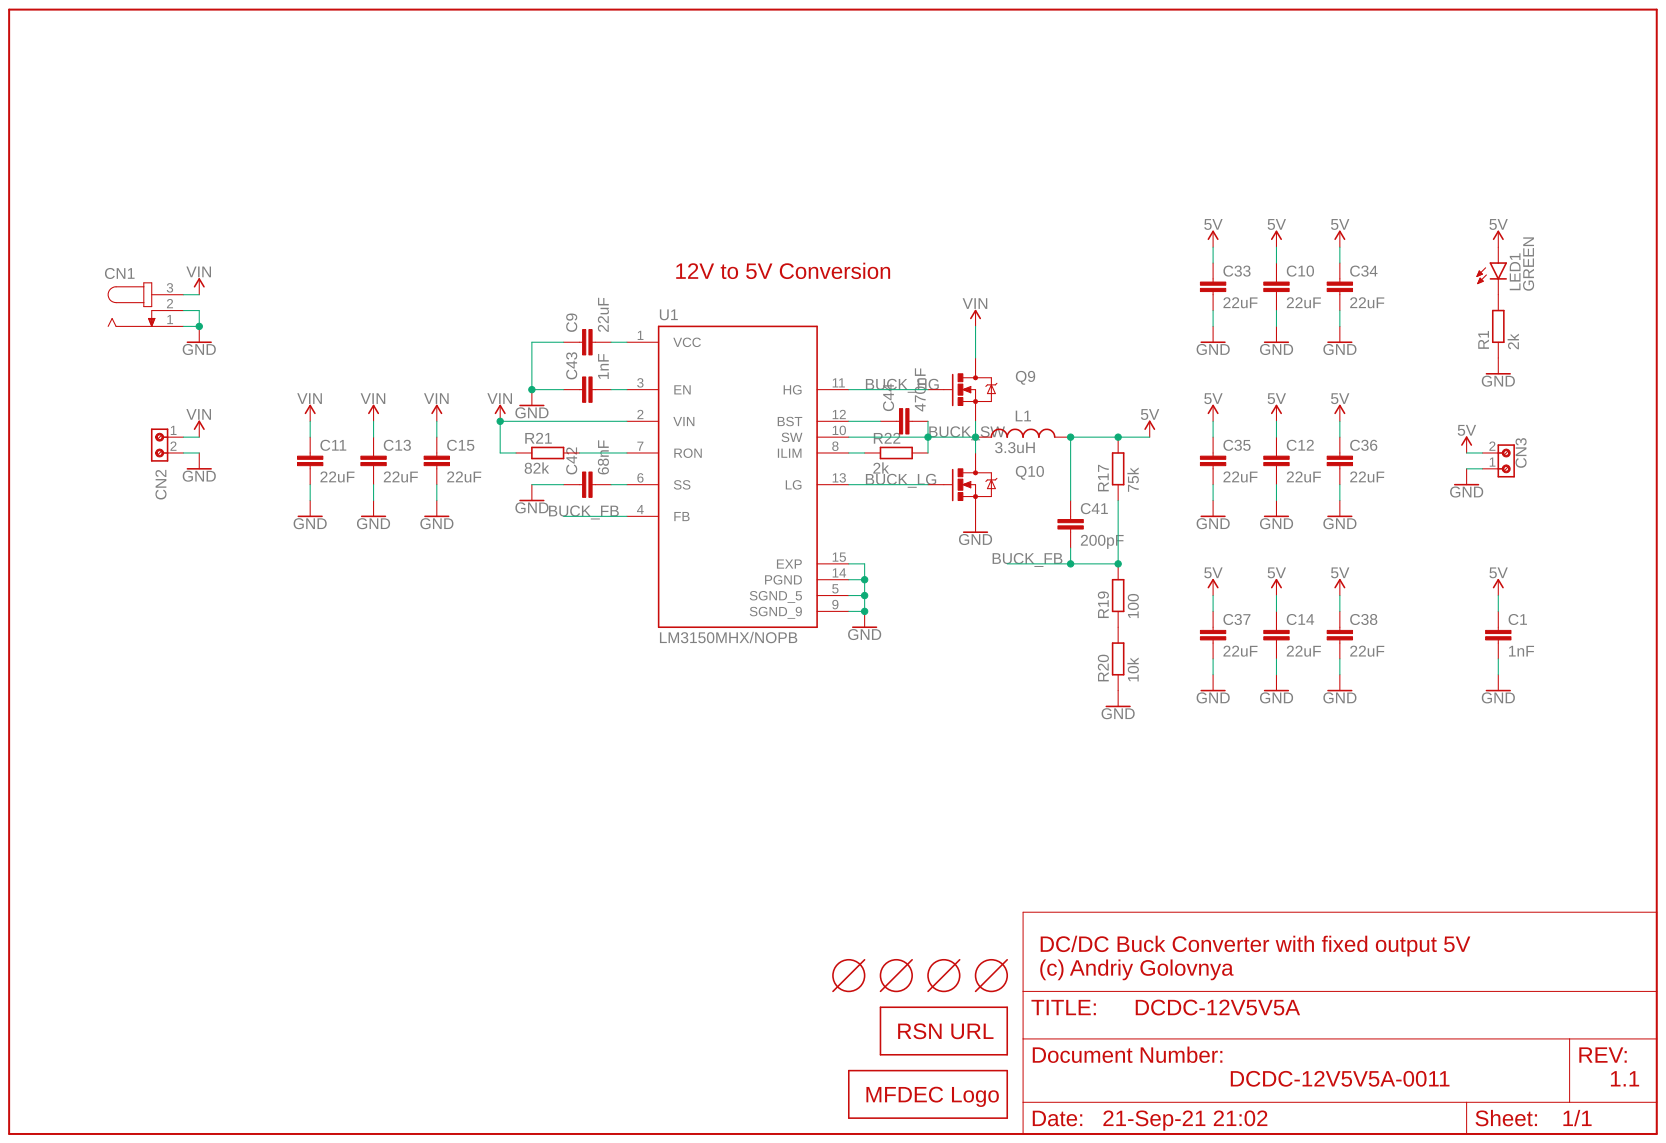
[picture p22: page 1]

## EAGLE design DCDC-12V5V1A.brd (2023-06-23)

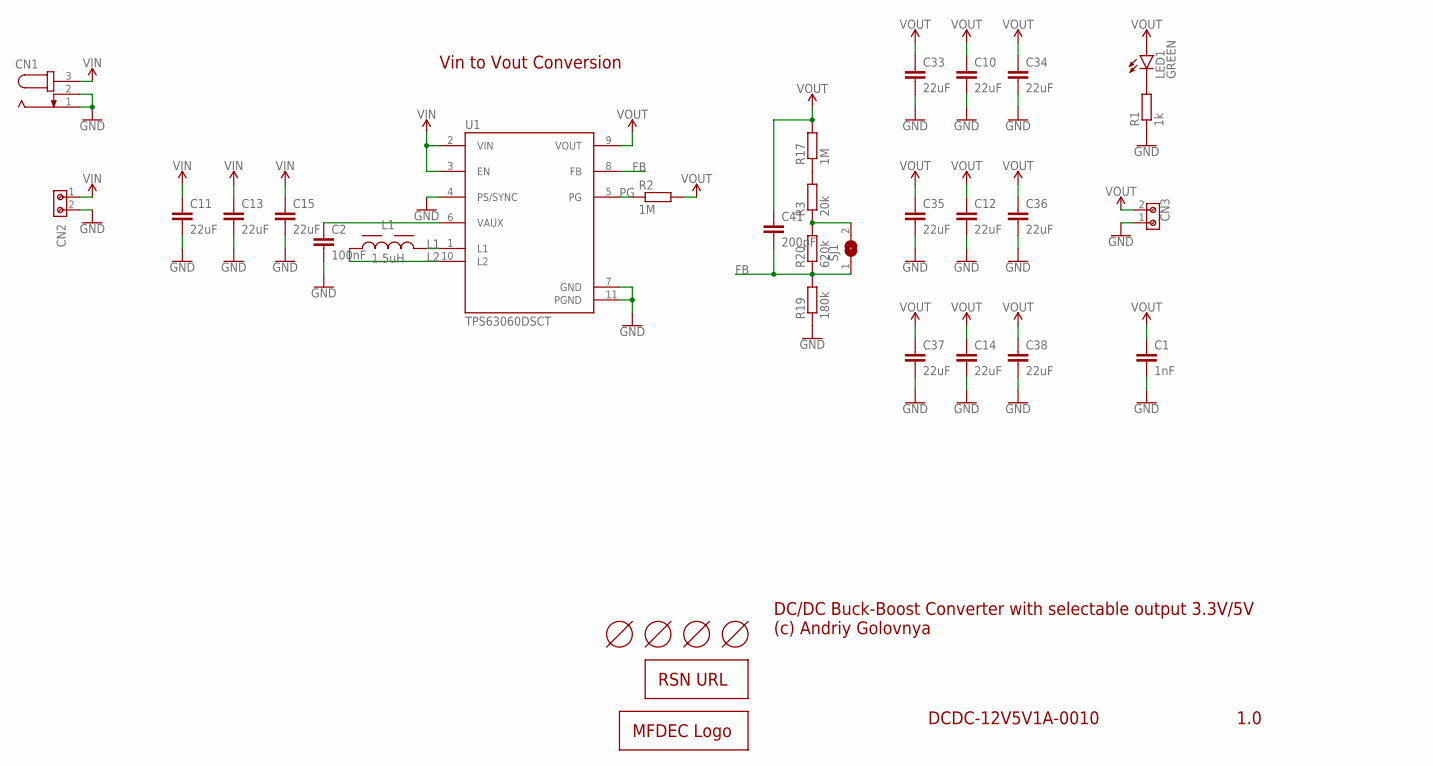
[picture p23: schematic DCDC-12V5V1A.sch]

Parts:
C1: 1nF; C0603K
C2: 100nF; C0603K
C10, C11, C12, C13, C14, C15, C33, C34, C35, C36, C37, C38: 22uF; C0805K
C41: 200pF; C0603K
CN1: JACK-PLUG1; SPC4078
CN2, CN3: 691213510002
HOLE1, HOLE2, HOLE3, HOLE4: TOOLINGHOLE; TOOLING-HOLE
L1: 1.5uH; WE-LQS_4018
LED1: GREEN; SML0603
LOGO1: RSNURL_QR_8MM
LOGO2: MFDECLOGO_L_10MM; MFDEC_L_10MM
R1: 1k; R0603
R2, R17: 1M; R0603
R3: 20k; R0603
R19: 180k; R0603
R20: 620k; R0603
SJ1: SJ
U1: TPS63060DSCT; CONV_TPS63060DSCT

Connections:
FB: C41.2, R19.2, R20.1, SJ1.1, U1.8 (FB)
GND: C1.2, C2.2, C10.2, C11.2, C12.2, C13.2, C14.2, C15.2, C33.2, C34.2, C35.2, C36.2, C37.2, C38.2, CN1.1, CN1.2, CN2.2, CN3.1, R1.1, R19.1, U1.4 (PS/SYNC), U1.7 (GND), U1.11 (PGND)
L1: L1.2, U1.1 (L1)
L2: L1.1, U1.10 (L2)
unnamed: LED1.C, R1.2
unnamed: R3.2, R17.1
unnamed: R3.1, R20.2, SJ1.2
PG: R2.1, U1.5 (PG)
VIN: C11.1, C13.1, C15.1, CN1.3, CN2.1, U1.2 (VIN), U1.3 (EN)
VINA: C2.1, U1.6 (VAUX)
VOUT: C1.1, C10.1, C12.1, C14.1, C33.1, C34.1, C35.1, C36.1, C37.1, C38.1, C41.1, CN3.2, LED1.A, R2.2, R17.2, U1.9 (VOUT)

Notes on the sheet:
1.0
DCDC-12V5V1A-0010
DC/DC Buck-Boost Converter with selectable output 3.3V/5V (c) Andriy Golovnya
Vin to Vout Conversion

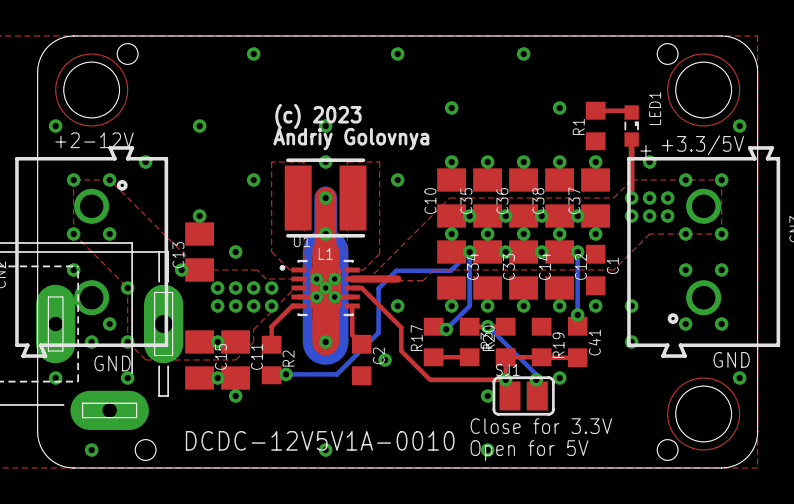
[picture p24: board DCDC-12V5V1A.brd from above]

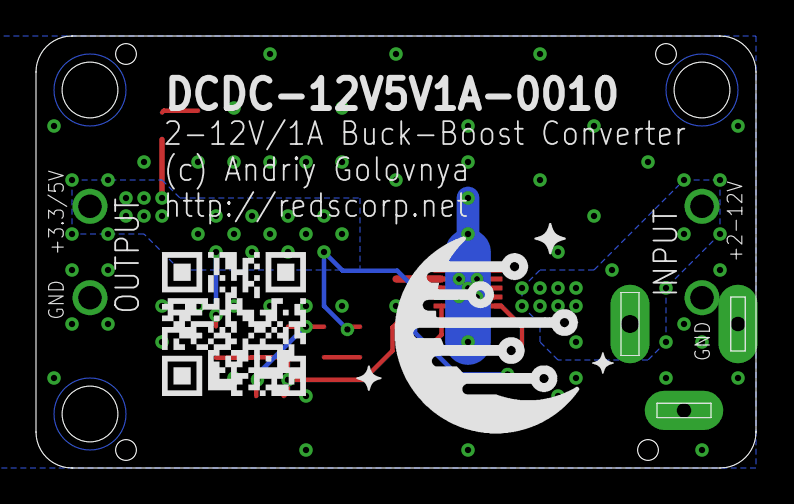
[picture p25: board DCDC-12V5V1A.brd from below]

Board: 2 copper layers, 40.0 x 24.0 mm, 34 parts (2 on the bottom side), 11 nets.

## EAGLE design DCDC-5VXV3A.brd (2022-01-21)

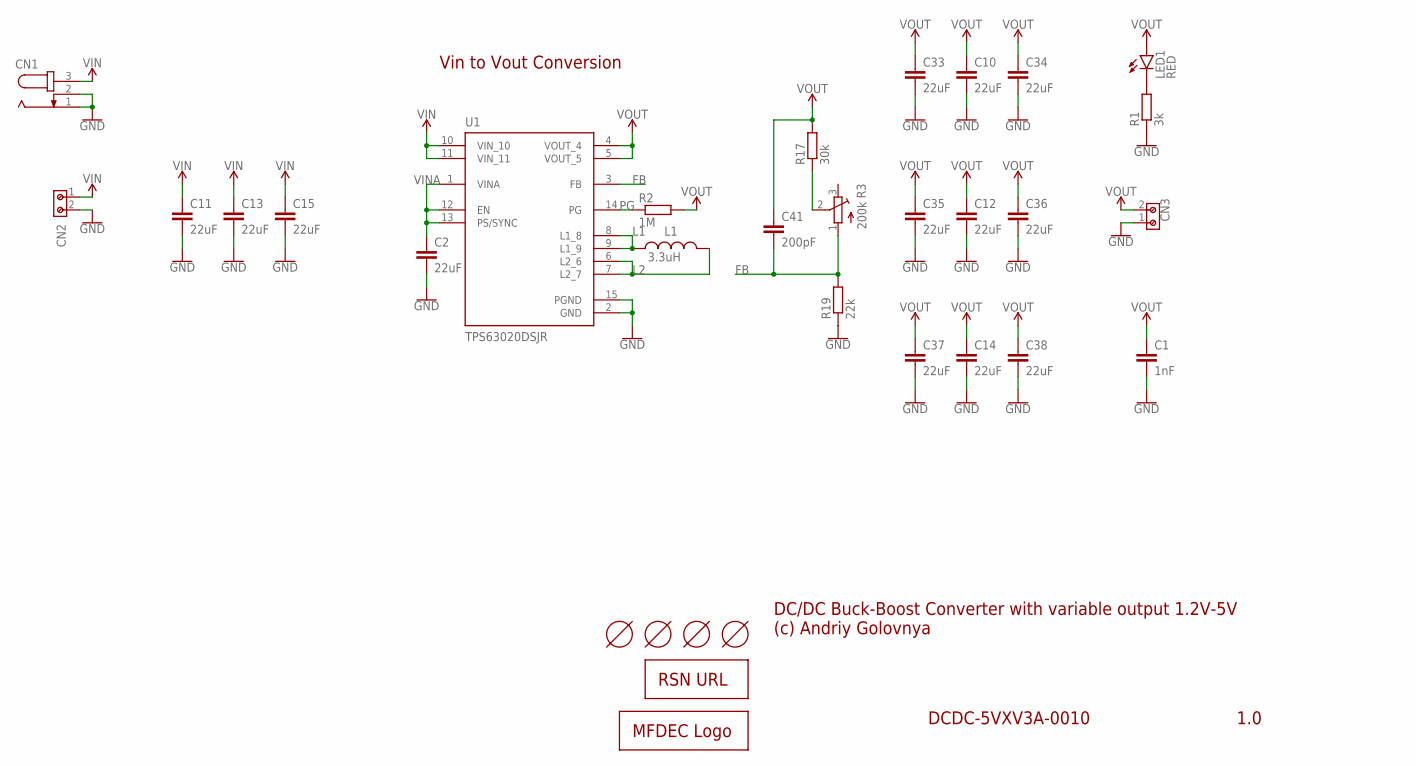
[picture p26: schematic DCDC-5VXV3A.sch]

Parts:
C1: 1nF; C0603K
C2, C10, C11, C12, C13, C14, C15, C33, C34, C35, C36, C37, C38: 22uF; C0805K
C41: 200pF; C0603K
CN1: JACK-PLUG1; SPC4078
CN2, CN3: 691213510002
HOLE1, HOLE2, HOLE3, HOLE4: TOOLINGHOLE; TOOLING-HOLE
L1: 3.3uH; WE-CHSA_1011
LED1: RED; SML0603
LOGO1: RSNURL_QR_8MM
LOGO2: MFDECLOGO_L_10MM; MFDEC_L_10MM
R1: 3k; R0603
R2: 1M; R0603
R3: 200k; TC33X
R17: 30k; R0603
R19: 22k; R0603
U1: TPS63020DSJR; IC_TPS63020DSJR

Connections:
FB: C41.2, R3.1 (A), R19.2, U1.3 (FB)
GND: C1.2, C2.2, C10.2, C11.2, C12.2, C13.2, C14.2, C15.2, C33.2, C34.2, C35.2, C36.2, C37.2, C38.2, CN1.1, CN1.2, CN2.2, CN3.1, R1.1, R19.1, U1.2 (GND), U1.15 (PGND)
L1: L1.1, U1.8 (L1_8), U1.9 (L1_9)
L2: L1.2, U1.6 (L2_6), U1.7 (L2_7)
unnamed: LED1.C, R1.2
unnamed: R3.2 (S), R17.1
PG: R2.1, U1.14 (PG)
VIN: C11.1, C13.1, C15.1, CN1.3, CN2.1, U1.10 (VIN_10), U1.11 (VIN_11)
VINA: C2.1, U1.1 (VINA), U1.12 (EN), U1.13 (PS/SYNC)
VOUT: C1.1, C10.1, C12.1, C14.1, C33.1, C34.1, C35.1, C36.1, C37.1, C38.1, C41.1, CN3.2, LED1.A, R2.2, R17.2, U1.4 (VOUT_4), U1.5 (VOUT_5)

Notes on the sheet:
1.0
DCDC-5VXV3A-0010
DC/DC Buck-Boost Converter with variable output 1.2V-5V (c) Andriy Golovnya
Vin to Vout Conversion

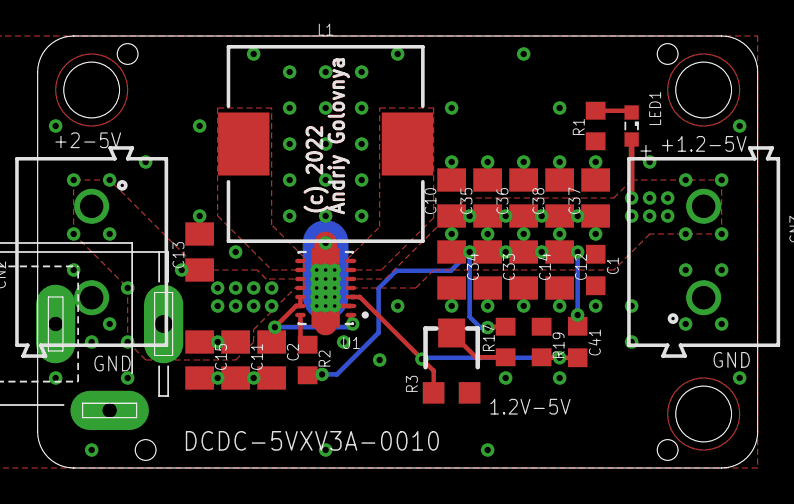
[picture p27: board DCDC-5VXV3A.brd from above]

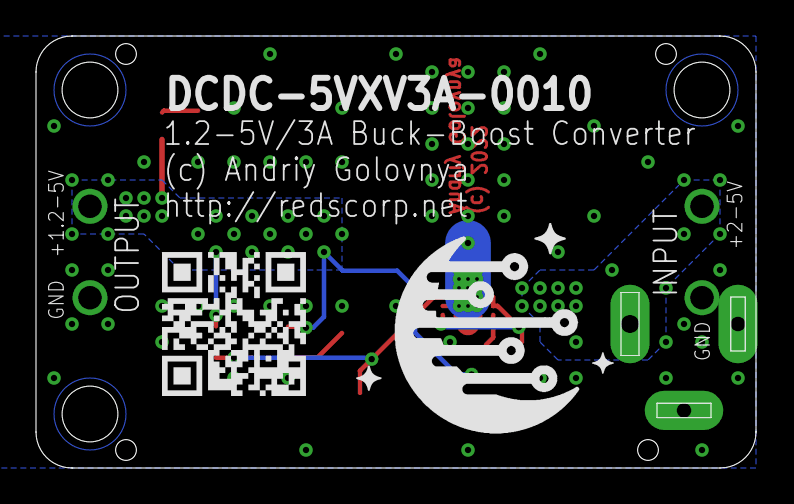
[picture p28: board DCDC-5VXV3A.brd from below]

Board: 2 copper layers, 40.0 x 24.0 mm, 32 parts (2 on the bottom side), 10 nets.

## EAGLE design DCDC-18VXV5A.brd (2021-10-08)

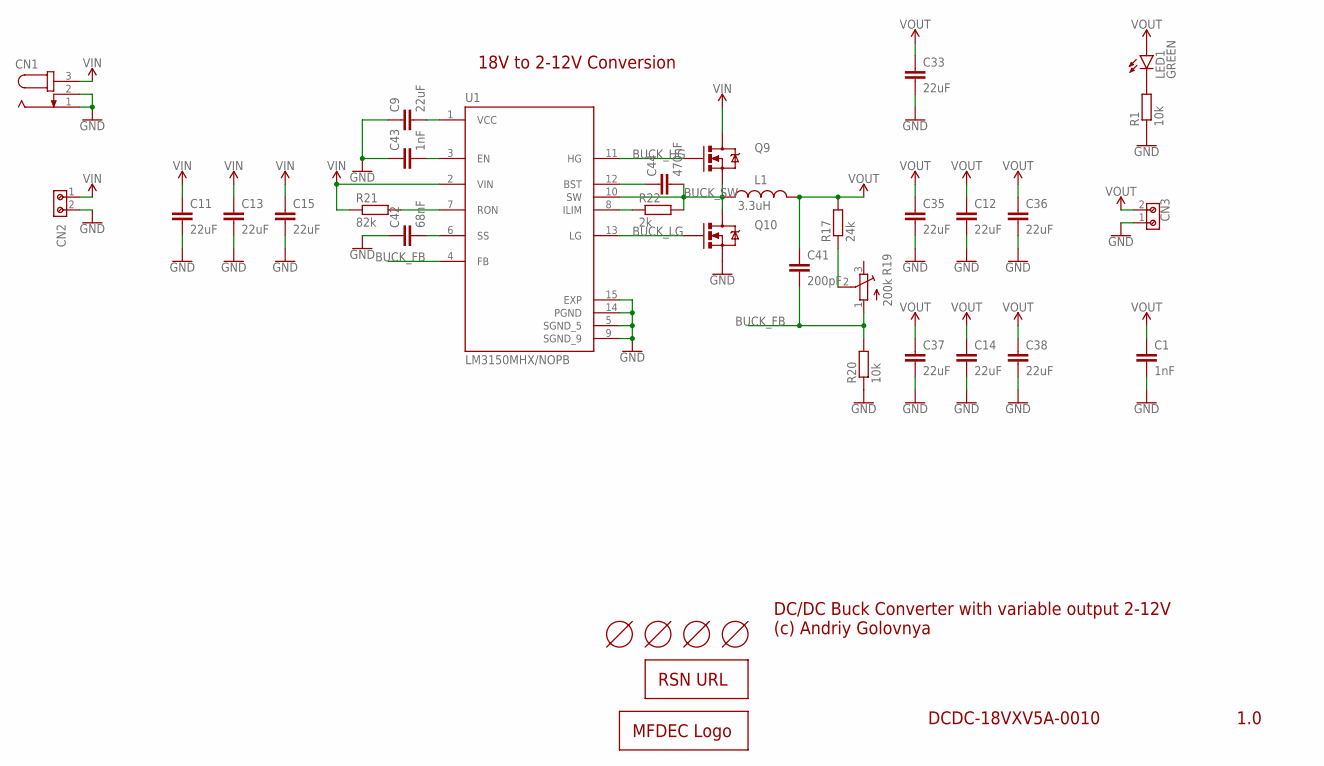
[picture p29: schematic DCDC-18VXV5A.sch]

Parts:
C1, C43: 1nF; C0603K
C9, C11, C12, C13, C14, C15, C33, C35, C36, C37, C38: 22uF; C0805K
C41: 200pF; C0603K
C42: 68nF; C0603K
C44: 470nF; C0603K
CN1: JACK-PLUG1; SPC4078
CN2, CN3: 691213510002
HOLE1, HOLE2, HOLE3, HOLE4: TOOLINGHOLE; TOOLING-HOLE
L1: 3.3uH; WE-CHSA_1011
LED1: GREEN; SML0603
LOGO1: RSNURL_QR_8MM
LOGO2: MFDECLOGO_L_10MM; MFDEC_L_10MM
Q9, Q10: NMOSFET; DPAK
R1, R20: 10k; R0603
R17: 24k; R0603
R19: 200k; TC33X
R21: 82k; R0603
R22: 2k; R0603
U1: LM3150MHX/NOPB; SOP65P640X110-15N

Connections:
BUCK_BST: C44.1, U1.12 (BST)
BUCK_EN: C43.2, U1.3 (EN)
BUCK_FB: C41.2, R19.1 (A), R20.2, U1.4 (FB)
BUCK_HG: Q9.1 (G), U1.11 (HG)
BUCK_ILIM: R22.1, U1.8 (ILIM)
BUCK_LG: Q10.1 (G), U1.13 (LG)
BUCK_RON: R21.2, U1.7 (RON)
BUCK_SS: C42.2, U1.6 (SS)
BUCK_SW: C44.2, L1.1, Q9.3 (S), Q10.4 (D), R22.2, U1.10 (SW)
BUCK_VCC: C9.2, U1.1 (VCC)
GND: C1.2, C9.1, C11.2, C12.2, C13.2, C14.2, C15.2, C33.2, C35.2, C36.2, C37.2, C38.2, C42.1, C43.1, CN1.1, CN1.2, CN2.2, CN3.1, Q10.3 (S), R1.1, R20.1, U1.5 (SGND_5), U1.9 (SGND_9), U1.14 (PGND), U1.15 (EXP)
unnamed: LED1.C, R1.2
unnamed: R17.1, R19.2 (S)
VIN: C11.1, C13.1, C15.1, CN1.3, CN2.1, Q9.4 (D), R21.1, U1.2 (VIN)
VOUT: C1.1, C12.1, C14.1, C33.1, C35.1, C36.1, C37.1, C38.1, C41.1, CN3.2, L1.2, LED1.A, R17.2

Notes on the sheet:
1.0
DCDC-18VXV5A-0010
DC/DC Buck Converter with variable output 2-12V (c) Andriy Golovnya
18V to 2-12V Conversion

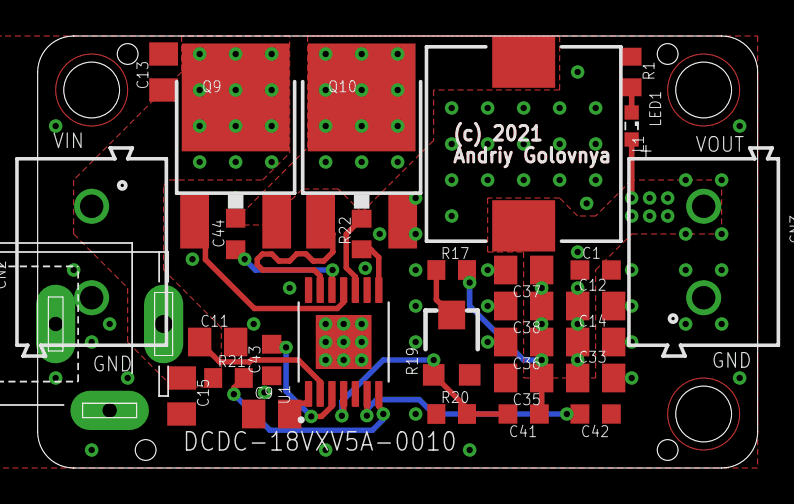
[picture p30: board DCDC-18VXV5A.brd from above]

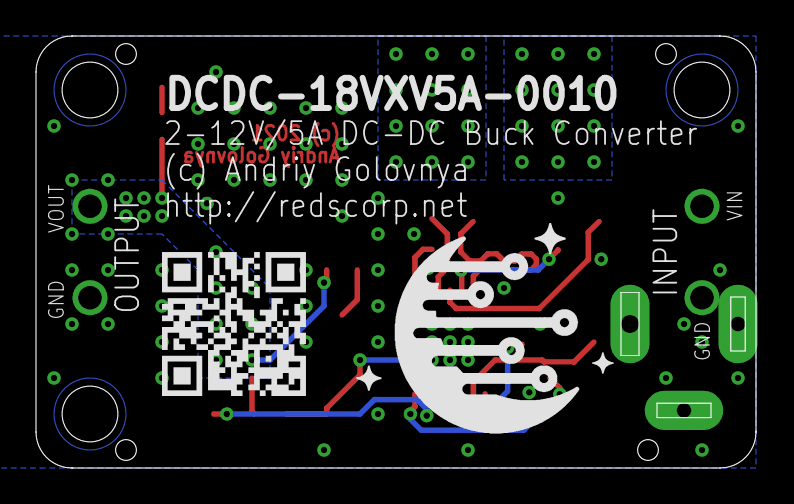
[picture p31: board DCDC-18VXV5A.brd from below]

Board: 2 copper layers, 40.0 x 24.0 mm, 36 parts (2 on the bottom side), 15 nets.

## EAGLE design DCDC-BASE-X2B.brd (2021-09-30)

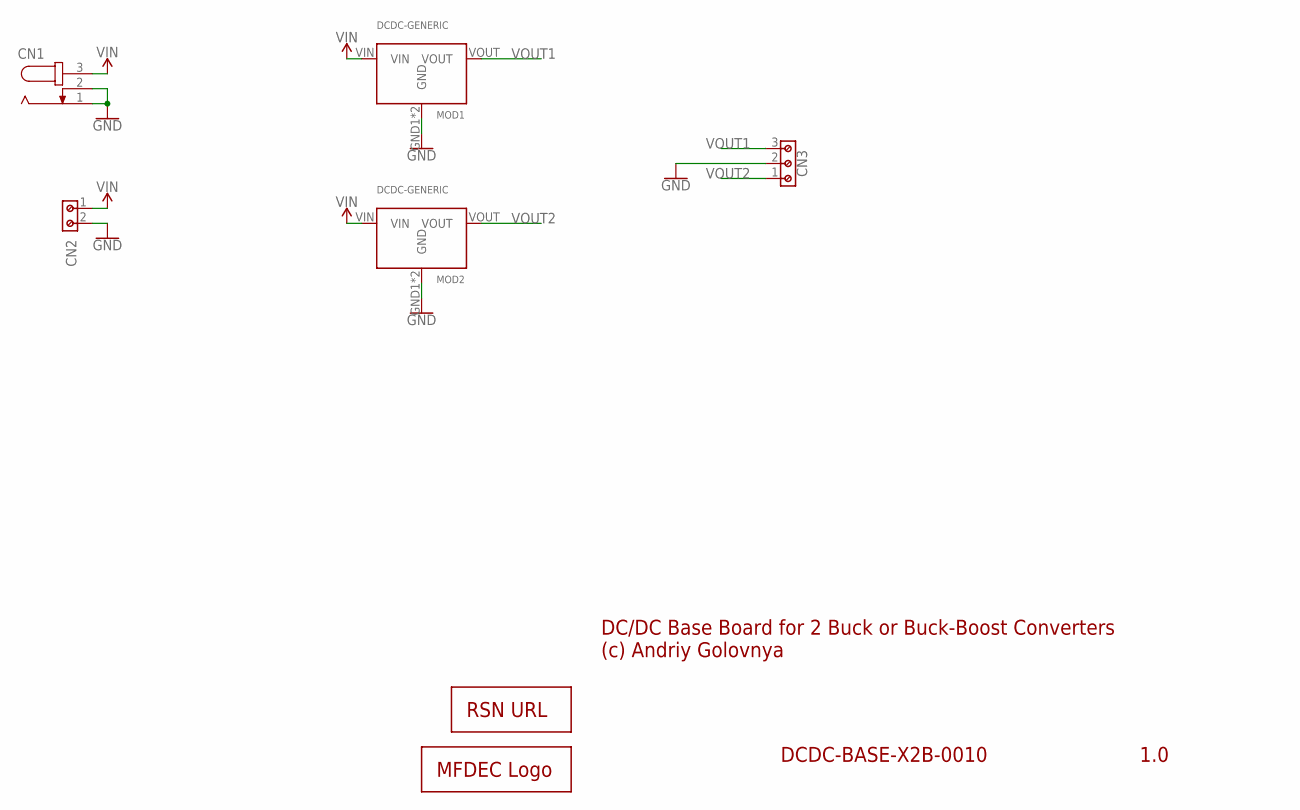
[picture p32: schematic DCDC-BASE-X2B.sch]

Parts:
CN1: JACK-PLUG1; SPC4078
CN2: 691213510002
CN3: 691213510003
LOGO1: RSNURL_QR_8MM
LOGO2: MFDECLOGO_L_10MM; MFDEC_L_10MM
MOD1, MOD2: DCDC-GENERIC; DCDC-BOARD

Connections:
GND: CN1.1, CN1.2, CN2.2, CN3.2, MOD1.GND1 (GND), MOD1.GND2 (GND), MOD2.GND1 (GND), MOD2.GND2 (GND)
VIN: CN1.3, CN2.1, MOD1.VIN, MOD2.VIN
VOUT1: CN3.3, MOD1.VOUT
VOUT2: CN3.1, MOD2.VOUT

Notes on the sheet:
1.0
DCDC-BASE-X2B-0010
DC/DC Base Board for 2 Buck or Buck-Boost Converters (c) Andriy Golovnya

Board: 2 copper layers, 7 parts (1 on the bottom side), 4 nets, no tracks yet.

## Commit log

2021-07-24 Add basic schematics of 12V-5V-5A DC-DC buck converter.
    [DCDC-12V5V5A.sch]
2021-07-24 Added board design. Added descriptive texts. Generated CAM files.
    [DCDC-12V5V5A.brd, DCDC-12V5V5A.sch]
2021-07-24 Fixed some placement. Generated CAM files.
    [DCDC-12V5V5A.brd]
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2021-07-25 Exchanged MOSFETs for bigger once. Generated CAM files. Generated BoM and PnP files.
    [DCDC-12V5V5A.brd, DCDC-12V5V5A.sch, DCDC-12V5V5A_2021-07-24-BoM.xlsx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]
2021-07-25 Added indication LED. Generated CAM files. Generated BoM and PnP files.
    [DCDC-12V5V5A.brd, DCDC-12V5V5A.sch, DCDC-12V5V5A_2021-07-25-BoM.xlsx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]
2021-07-26 Minor improvements in board routing. Generated CAM files. Fixed footprints in BoM.
    [DCDC-12V5V5A.brd, DCDC-12V5V5A_2021-07-25-BoM.xlsx]
2021-07-26 Minor improvements in board routing. Generated CAM files.
    [DCDC-12V5V5A.brd]
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2021-08-08 Added copper thermal pads at the back of the board.
    [DCDC-12V5V5A.brd]
2021-08-09 Added more space between fills. Generated CAM files.
    [DCDC-12V5V5A.brd]
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2021-08-15 Added calculation for 3.3v and 12v buck converters.
    [LM3150MHX Calculator.xlsx]
2021-08-17 Renamed 12V line to Vin. Generated CAM files.
    [DCDC-12V5V5A.brd, DCDC-12V5V5A.sch]
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2021-08-17 Fixed few values on 3.3V schematics. Generated CAM files.
    [DCDC-12V3V5A.brd, DCDC-12V3V5A.sch, LM3150MHX Calculator.xlsx]
2021-08-17 Text fixed.
    [DCDC-12V3V5A.sch]
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2021-08-30 Made new layout of DC-DC board. Improved XLS calculator. Generated CAM files. Generated BoM and PnP files. Generated PNG preview. Generated PDF schematics.
    [DCDC-12V5V5A.brd, DCDC-12V5V5A.sch, DCDC-12V5V5A_2021-08-17-BoM.xlsx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]
2021-08-30 Improved layout of DC-DC board. Rotated input terminal. Improved XLS calculator. Generated CAM files. Generated BoM and PnP files. Generated PNG preview. Generated PDF schematics.
    [DCDC-12V5V5A.brd, DCDC-12V5V5A.sch, DCDC-12V5V5A_2021-08-29-PnP.xlsx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]
2021-08-30 Fixed 5V board BoM.
    [DCDC-12V5V5A_2021-08-30-BoM.xlsx]
2021-08-30 Improved layout of DC-DC board. Rotated input terminal. Generated CAM files. Generated BoM and PnP files. Generated PNG preview. Generated PDF schematics.
    [DCDC-12V3V5A.brd, DCDC-12V3V5A.csv, DCDC-12V3V5A.sch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]
2021-08-30 Fixed text on schematics. Generated PDF schematics. Removed wrongly committed CSV file.
    [DCDC-12V3V5A.csv, DCDC-12V3V5A.sch, DCDC-12V5V5A.sch]
2021-08-31 Added proper voltage symbols on 3.3v and 12v boards. Generated PDF schematics.
    [DCDC-12V3V5A.brd, DCDC-12V3V5A.sch, DCDC-17V12V5A.brd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]
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2021-09-10 Improved schematics and routing of 5V-5V board. Generated PDF schematics. Generated PNG preview. Generated CAM files.
    [DCDC-5V5V3A.brd, DCDC-5V5V3A.sch, TPS63020 Calculator.xlsx]
2021-09-10 Improved routing of 5V-5V board. Generated PNG preview. Generated CAM files.
    [DCDC-5V5V3A.brd]
2021-09-11 Fixed few traces. Generated CAM files. Generated PNG preview.
    [DCDC-5V5V3A.brd]
2021-09-18 Moved some texts and tooling holes a bit. Generated CAM files. Generated PNG preview. Generated PDF schematics. Renamed BoM and PnP files.
    [DCDC-12V3V5A.brd, DCDC-12V3V5A.sch, DCDC-12V3V5A_2021-09-18-BoM.xlsx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]
2021-09-21 Added 200k resistor to improve voltage output. Generated CAM files. Generated PNG preview. Generated PDF schematics. Adjusted BoM and PnP files. Adjusted Excel calculator.
    [DCDC-5V5V3A.brd, DCDC-5V5V3A.sch, DCDC-5V5V3A_2021-09-18-BoM.xlsx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]
2021-09-21 Fixed typo. Generated PDF schematics.
    [DCDC-12V3V5A.sch, DCDC-12V5V5A.sch, DCDC-17V12V5A.sch]
2021-09-21 Fixed PnP file.
    [DCDC-5V5V3A_2021-09-21-PnP.xlsx]
2021-09-21 Changed font size. Generated CAM files. Generated PNG preview.
    [DCDC-5V5V3A.brd]
2021-09-21 fixed schematics description. Generated PDF schematics.
    [DCDC-5V5V3A.sch]
2021-09-22 Added x2 base board. Generated CAM files. Generated PNG preview. Generated PDF schematics.
    [DCDC-BASE-X2.brd, DCDC-BASE-X2.sch]
2021-09-23 Small fixes. Generated PNG preview. Generated CAM files.
    [DCDC-BASE-X2.brd, DCDC-BASE-X2.sch]
2021-09-23 Added 3d enclosure. Generated STL model. Updated README.
    [DCDC-BOX.scad, DCDC-BOX.stl]
2021-09-24 Added few texts. Generated PNG preview. Generated CAM files.
    [DCDC-BASE-X2.brd]
2021-09-25 Renamed X2 board to X2A. Generated CAM files. Generated PNG preview. Generated PDF schematics. Updated descriptions.
    [DCDC-BASE-X2A.brd, DCDC-BASE-X2A.sch]
2021-09-25 Added x2B board. Generated CAM files. Generated PNG preview. Generated PDF schematics. Updated description.
    [DCDC-BASE-X2B.brd, DCDC-BASE-X2B.sch]
2021-09-25 Added x2 box 3d model. Generated STL model. Generated PNG preview. Updated description.
    [DCDC-BOX-X2.scad, DCDC-BOX-X2.stl]
2021-09-26 Added few vias. Generated CAM files. Generated PNG preview. Renamed BoM and PnP files.
    [DCDC-12V3V5A.brd, DCDC-12V3V5A_2021-09-26-BoM.xlsx, DCDC-12V3V5A_2021-09-26-PnP.xlsx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]
2021-09-30 Moved some stuff around on x2 boards. Generated CAM files. Generated PNG preview.
    [DCDC-BASE-X2A.brd, DCDC-BASE-X2B.brd]
2021-10-03 Added variable version of buck converter board. Generated PNG preview. Generated PDF schematics.
    [DCDC-17VXV5A.brd, DCDC-17VXV5A.sch]
2021-10-05 Changed LEDs resistor. Generated CAM filers. Generated PNG preview. Generated PDF schematics. Updated description.
    [DCDC-17VXV5A.brd, DCDC-17VXV5A.sch]
2021-10-06 Added board name to the top of the board too. Generated CAM files. Generated PNG preview.
    [DCDC-12V3V5A.brd, DCDC-12V5V5A.brd, DCDC-17V12V5A.brd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]
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2021-10-07 Changed texts on 18V-12V boards. Generated CAM files. Generated PNG preview. Generated PDF schematics.
    [DCDC-18V12V5A.brd, DCDC-18V12V5A.sch, DCDC-18VXV5A.brd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]
2021-10-08 Renamed VOUT line. Generated CAM files. Generated PNG preview. Generated PDF schematics.
    [DCDC-18VXV5A.brd, DCDC-18VXV5A.sch]
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2022-01-21 Added new step-up/down board. Generated CAM files. Generated PNG preview. Generated PDF schematics. Generated BoM and PnP files. Updated descriptions. Updated XLS calculator.
    [DCDC-5VXV3A.brd, DCDC-5VXV3A.sch, DCDC-5VXV3A_2022-01-21-BoM.xlsx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]
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2023-06-23 Changed L1 inductor from 1uH to 1.5uH for higher output current stability. Generated PDF schematics. Updated BoM file.
    [DCDC-12V5V1A.brd, DCDC-12V5V1A.sch, DCDC-12V5V1A_2023-06-18-BoM.xlsx]
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

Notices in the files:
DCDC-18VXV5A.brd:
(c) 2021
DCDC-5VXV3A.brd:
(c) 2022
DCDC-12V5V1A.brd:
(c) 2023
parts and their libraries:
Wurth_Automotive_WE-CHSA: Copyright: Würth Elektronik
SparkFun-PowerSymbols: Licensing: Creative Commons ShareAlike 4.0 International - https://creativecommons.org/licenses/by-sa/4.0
